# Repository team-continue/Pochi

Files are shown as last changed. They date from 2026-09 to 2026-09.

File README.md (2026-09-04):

# Pochi
CoREストライダー部門用のロボット「Pochi」のメインレポジトリです。

詳細はドキュメントサイトを参照してください。

## 開発ルール
開発はブランチを切って Pull Request で main にマージしてください。main への直接コミットは禁止です。
ブランチ名: 機能追加は feature/hogehoge、バグ修正は fix/hogehoge
パッケージ名: pochi_hoge（タブ補完で一覧表示できるように）
Formatting (CI)
Push 時に CI が ament_clang_format を実行し、必要ならブランチへ自動コミットします。 main ブランチには自動 push しません。

## ビルド
``` shell
cd ~/ros2_ws
source /opt/ros/humble/setup.bash
rosdep install --from-paths src -i -y
colcon build --symlink-install
source install/setup.bash
```

## 起動方法
```
# シミュレータモード（デフォルト: /sim_odom使用）
ros2 launch core_launch navigation.launch.py

# シミュレータ + FAST-LIOオドメトリ
ros2 launch core_launch navigation.launch.py odom_source:=fastlio

# 実機モード（FAST-LIO + body_controller、TCP endpoint無し）
ros2 launch core_launch navigation.launch.py environment:=real

# 実機モード（GUI・ショートカットから）
# .bashrc が非対話シェルで早期 return するため、このラッパーを使用
ros2 run core_launch navigation.sh

# ボディコントローラ単体
ros2 launch core_launch navigation.launch.py environment:=real map_name:=curious_house.png

```
Launch 引数の詳細はドキュメントサイトの「クイックスタート」を参照してください。

実機ハードウェア、Teensy通信、Web joint viewerのセットアップは
[`pochi_hardware/README.md`](pochi_hardware/README.md)を参照してください。

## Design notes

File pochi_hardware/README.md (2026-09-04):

# Pochi Hardware

Pochiの回路、STM32/Teensyファームウェア、ホスト側通信ツール、Python API、
Web joint viewerをまとめています。

## Python APIとWeb joint viewer

`pochi_client`はTeensy USB/UDP bridgeと通信するPython APIです。12台分のMIT指令を
1 packetで送信し、12台の状態とIMUを1 packetで受信します。Web viewerは左側の
3Dモデルへ現在姿勢を反映し、右側から関節の選択・目標角度・全体Torque ON/OFFを
操作できます。

### セットアップ

```bash
cd ~/Documents/GitHub/Pochi
uv sync

cd pochi_hardware/web
npm install
```

### Web joint viewer

3つのターミナルを使います。

#### 1. USB/UDP bridge

macOSではTeensyのdevice名を確認して起動します。

```bash
cd ~/Documents/GitHub/Pochi
uv run python pochi_hardware/src/teensy_udp_bridge.py \
  --serial /dev/cu.usbmodem176277501 \
  --command-bind 127.0.0.1:15000 \
  --state-dest 127.0.0.1:15001
```

#### 2. UDP/WebSocket server

```bash
cd ~/Documents/GitHub/Pochi
uv run python -m pochi_hardware.web.server
```

状態確認用URLは`http://127.0.0.1:8765/health`、WebSocketは
`ws://127.0.0.1:8765/ws`です。

#### 3. Web UI

```bash
cd ~/Documents/GitHub/Pochi/pochi_hardware/web
npm run dev
```

ブラウザで`http://127.0.0.1:3000`を開きます。

### Viewer controls and safety

- 左の3Dモデルは12軸の実角度を常時反映します。ドラッグで視点回転、スクロールでズーム、関節をクリックすると選択できます。
- 右の関節一覧または3Dモデルから1軸を選び、スライダーでMIT controlの目標角を更新します。
- `TORQUE ON`は全12台の現在角を初期目標に設定してから全軸をEnableします。
- 全12台から有効なCAN feedbackが返り、Faultがないときだけ`TORQUE ON`できます。
- 最後のWeb画面を閉じた場合、WebSocket serverは全軸を自動Disableします。
- WebSocket server終了時は全軸Disableとemergency-stop packetを送ります。
- Hip/Thigh/Calfの暫定UI制限はそれぞれ±55°、±150°、-165〜25°です。機構限界確定後にWeb UIとserverの両方を更新してください。

### Client API

```python
from pochi_client import PochiClient

with PochiClient() as robot:
    state = robot.wait_for_state(timeout=1.0)
    robot.set_mit(
        "front_left_hip",
        position_rad=0.2,
        velocity_rad_s=0.0,
        kp=20.0,
        kd=0.5,
        torque_nm=0.0,
        enable=True,
    )
    robot.disable_all()
```

### Joint layout

脚とCAN IDの対応です。各脚では足先側からIDが増えます。

| Leg | Hip | Thigh | Calf |
| --- | ---: | ---: | ---: |
| Front left | 2 | 1 | 0 |
| Rear left | 5 | 4 | 3 |
| Rear right | 8 | 7 | 6 |
| Front right | 11 | 10 | 9 |

Web画面には誤認防止のためCAN IDを常時表示します。

### テストとWebビルド

```bash
cd ~/Documents/GitHub/Pochi
uv run pytest -q

cd pochi_hardware/web
npm run build
```

## Jetson Orin NanoのSPI0ピン設定

`systemd/pochi-spi0-pinmux.service`は、Jetson Orin Nanoの40ピンヘッダーにある
SPI0をPochi用に設定します。

使用する物理ピンは次の4本です。

| 物理ピン | 信号 |
| --- | --- |
| 19 | SPI0 MOSI |
| 21 | SPI0 MISO |
| 23 | SPI0 SCK |
| 24 | SPI0 CS0 |

### インストールと有効化

以下は、この`pochi_hardware`ディレクトリで実行します。

```bash
sudo install -o root -g root -m 0644 \
  systemd/pochi-spi0-pinmux.service \
  /etc/systemd/system/pochi-spi0-pinmux.service

sudo systemctl daemon-reload
sudo systemctl enable --now pochi-spi0-pinmux.service
sudo systemctl restart pochi-spi0-pinmux.service
```

状態を確認します。

```bash
systemctl is-enabled pochi-spi0-pinmux.service
systemctl is-active pochi-spi0-pinmux.service
```

それぞれ`enabled`と`active`になれば設定完了です。

### STM32との通信確認

STM32へSPIエコーファームウェアを書き込んだ状態で、Orinから20 MHzのテストを
実行します。

```bash
cd ~/pochi
./orin_spi_test /dev/spidev0.0 20000000
```

成功時は次のように表示されます。

```text
TX=DE AD BE E1  ECHO=DE AD BE E1
PASS: STM32 echoed the Orin request
```

### 停止とGPIO設定の復元

サービスを停止すると`ExecStop`が実行され、SPIパッドを開発用Orinで取得した
元のGPIO設定へ戻します。

```bash
sudo systemctl disable --now pochi-spi0-pinmux.service
```

サービス自体も削除する場合は、停止後に次を実行します。

```bash
sudo rm -f /etc/systemd/system/pochi-spi0-pinmux.service
sudo systemctl daemon-reload
```

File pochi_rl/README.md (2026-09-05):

# Pochi RL

Standalone uv-managed reinforcement-learning project for the Pochi quadruped.
Phase 1 targets mjlab with a starter 4-leg x 3-DoF MJCF and a flat-ground
velocity-tracking PPO task. Phase 2 can add Isaac Lab configs while reusing the
same `task_spec.py` and robot constants.

## Setup

```bash
cd /home/k_suzuki/fun_ws/Pochi/pochi_rl
uv sync
uv pip install -e .
```

## Inspect the Robot

```bash
uv run python scripts/view_mjcf.py
```

## Train

Single GPU:

```bash
MUJOCO_GL=egl uv run train Pochi-Velocity-Flat-v0 \
  --env.scene.num-envs 4096 \
  --agent.max-iterations 1500 \
  --agent.experiment-name pochi_velocity_flat
```

Multi GPU:

```bash
MUJOCO_GL=egl uv run train Pochi-Velocity-Flat-v0 \
  --env.scene.num-envs 4096 \
  --gpu-ids "[0,1]"
```

Playback:

```bash
uv run play Pochi-Velocity-Flat-v0 \
  --checkpoint-file logs/rsl_rl/pochi_velocity_flat/<ts>/model_1500.pt \
  --num-envs 1
```

Export:

```bash
uv run python scripts/export_policy.py \
  --checkpoint logs/rsl_rl/pochi_velocity_flat/<ts>/model_1500.pt \
  --output exports/
```

## Notes

- The MJCF uses primitive collision/visual geometry only. Keep collision
  primitives when CAD meshes arrive unless a task needs detailed contacts.
- Joint names and action order are defined in
  `src/pochi_rl/robot/pochi_constants.py`.
- The default control path is MuJoCo position actuators with `kp=40`,
  `forcerange="-30 30"`, and policy deltas scaled by `action_scale=0.25`.
- Masses, inertias, dimensions, joint limits, and the default crouch are starter
  values and should be replaced with CAD/hardware values before sim-to-real.

## MPC Walking (No Training)

```bash
uv run --extra mpc python scripts/play_mpc_walk.py --port 8092
```

Open `http://localhost:8092` for live MuJoCo walking with MPC trajectory and
contact-force overlays. See [MPC_WALK.md](MPC_WALK.md) for evaluation, controls,
and the controller's scope.

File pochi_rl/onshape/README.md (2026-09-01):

# Onshape CAD Import

Exports the Pochi CAD assembly from Onshape to MJCF using
[onshape-to-robot](https://onshape-to-robot.readthedocs.io/).

## Setup (once)

1. Create API keys at <https://cad.onshape.com/user/developer/apiKeys>.
2. `cp .env.example .env` and fill in the keys (`.env` is gitignored).
3. Paste the Onshape **assembly** URL into `config.json` (`url`).

## Export

```bash
cd pochi_rl
uv run onshape-to-robot onshape/
```

Outputs `onshape/pochi_cad.xml` plus meshes in `onshape/assets/`. Preview with:

```bash
uv run onshape-to-robot-mujoco onshape/
```

## Required conventions in the Onshape assembly

onshape-to-robot derives the robot structure from mate-connector names
(see the [design page](https://onshape-to-robot.readthedocs.io/en/latest/design.html)).
Names must match `src/pochi_rl/robot/pochi_constants.py` so the exported model
is a drop-in for the training pipeline:

- The **first instance** in the top-level assembly is the base link. Attach a
  mate connector named `link_base_link` to name it `base_link`.
- **Joints** (12): revolute mates named `dof_<LEG>_<KIND>` for each leg
  `FL, FR, RL, RR` and kind `hip_roll, hip_pitch, knee`
  (e.g. `dof_FL_hip_roll`). Joints rotate around the mate's z-axis; append
  `_inv` (e.g. `dof_FL_knee_inv`) where needed to match the sign conventions
  in `assets/pochi/README.md`: hip pitch positive swings the leg backward,
  knee positive swings the shank backward, hip roll positive swings
  both legs to the robot's left.
- **Sites**: mate connectors `frame_FL_foot_site`, `frame_FR_foot_site`,
  `frame_RL_foot_site`, `frame_RR_foot_site` at the foot centers, and
  `frame_imu` on the torso. These become MuJoCo sites.
- Frames: torso x-forward, y-left, z-up.

## Integration into training assets

Per project policy (`assets/pochi/README.md`), CAD meshes replace **visual**
geoms only; the primitive **collision** geoms in `assets/pochi/pochi.xml`
(`<LEG>_foot_collision`, `<LEG>_thigh_collision`, `<LEG>_shank_collision`,
`base_collision`) stay, because the contact sensors and rewards in
`velocity_flat_env_cfg.py` reference them by name. After a satisfactory
export:

1. Compare masses/inertias/joint placements against `pochi.xml` and update the
   hand-written model with the CAD values.
2. Copy meshes into `assets/pochi/meshes/` and reference them as visual geoms.
3. `uv run pytest` — `test_mjcf_loads.py` pins joint/actuator/body counts.

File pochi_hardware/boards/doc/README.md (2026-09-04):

# Hardware reference documents

2026-08-23 に `main_1` 回路図を照合するため収集した資料です。
可能なものはメーカー公式PDFを保存し、メーカーサイトが直接取得を拒否する場合のみ、同一メーカー文書の配布ミラーを利用しています。

| 対象 | ローカル資料 | 公式の最新版・製品ページ | 備考 |
|---|---|---|---|
| STM32G474CB | `ST_STM32G474_datasheet.pdf` | https://www.st.com/resource/en/datasheet/stm32g474cb.pdf | DS12288 Rev.6 |
| STM32G4 hardware guide | 未保存 | https://www.st.com/resource/en/application_note/an5093-getting-started-with-stm32g4-series--hardware-development-boards-stmicroelectronics.pdf | AN5093 Rev.2。STサーバーがCLI取得を拒否するためリンクのみ |
| ICM-45686 | `TDK_ICM-45686_datasheet.pdf` | https://invensense.tdk.com/wp-content/uploads/documentation/DS-000577_ICM-45686.pdf | DS-000577 Rev.1.0。配布ミラーから保存 |
| S9012 / C8543 | `JSCJ_S9012_C8543_datasheet.pdf` | https://www.jscj-elec.com/gallery/file/AD-S9012%20series.pdf | メーカー公式PDF。C8543はSOT-23、hFE 200–350品 |
| SMCJ43A | `Bourns_SMCJ_datasheet.pdf` | https://www.bourns.com/docs/Product-Datasheets/SMCJ.pdf | 同一電気仕様のBourns公式シリーズ資料。採用時はメーカーとMPNを固定する |
| DDZ9699 12 V Zener | `Diodes_DDZ9699_datasheet.pdf` | https://www.diodes.com/part/view/DDZ9699 | LTC4359のGATE–SOURCE保護候補、SOD-123 |
| RobStride discharge module | `RobStride_discharge_module_manual_V1.1.pdf` | https://github.com/RobStride/Product_Information/tree/main/%E4%BA%A7%E5%93%81%E8%B5%84%E6%96%99/dischargeModule | 15–60 V、48 Vモードは53.5 Vで泄放開始。3 Ω/500 W～10 Ω/200 Wを推奨 |
| RobStride power board | `RobStride_power_board_manual_V1.5.pdf` | https://github.com/RobStride/Product_Information/tree/main/%E4%BA%A7%E5%93%81%E8%B5%84%E6%96%99/powerBoard | 20–65 V、4支路、プリチャージ・泄放・過流保護の構成参考 |
| TPS5430 | `TI_TPS5430_datasheet.pdf` | https://www.ti.com/lit/ds/symlink/tps5430.pdf | 公式PDF |
| ISO1044 | `TI_ISO1044_datasheet.pdf` | https://www.ti.com/lit/ds/symlink/iso1044.pdf | 公式PDF |
| ADuM120N/ADuM121N | `ADI_ADuM120N_ADuM121N_datasheet_RevE.pdf` | https://www.analog.com/media/en/technical-documentation/data-sheets/ADuM120N_121N.pdf | ローカルはRev.E。設計判断は公式Rev.Fを参照 |
| LTC4359 | `ADI_LTC4359_datasheet_RevE.pdf` | https://www.analog.com/media/en/technical-documentation/data-sheets/ltc4359.pdf | ローカルはRev.E。設計判断は公式Rev.Fを参照 |
| HT75xx-1 | `Holtek_HT75xx-1_datasheet.pdf` | https://www.holtek.com/webapi/116711/HT75xx-1v130.pdf | 公式PDF |
| MAU100 series | `MINMAX_MAU100_datasheet.pdf` | https://www.minmaxpower.com/storage/media/Product-MINMAX/MAU100/Document/MAU100_Datasheet.pdf | 公式PDF |
| SP3485 | `MaxLinear_SP3485_datasheet.pdf` | https://www.maxlinear.com/ds/sp3485.pdf | 公式PDF |
| SP481E/SP485E | `MaxLinear_SP481E_SP485E_datasheet.pdf` | https://www.maxlinear.com/ds/sp481e_sp485e.pdf | 公式PDF |
| IPT015N10NF2S | `Infineon_IPT015N10NF2S_datasheet.pdf` | https://www.infineon.com/part/IPT015N10NF2S | 公式PDF |
| 2N7002 | `onsemi_2N7002_datasheet.pdf` | https://www.onsemi.com/pdf/datasheet/2n7002-d.pdf | 公式PDF |
| Epson水晶型番体系 | `Epson_crystal_product_configuration.pdf` | https://www.epsondevice.com/crystal/en/support/product-no/pdf/pcs_xtal.pdf | Y1の正確な型番決定用 |
| Littelfuse SMDJ | 未保存 | https://www.littelfuse.com/assetdocs/littelfuse-tvs-diode-smdj-datasheet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 | 公式サーバーがCLI取得を403拒否するためリンクのみ |
| Jetson Orin Nano carrier | `NVIDIA_Jetson_Orin_Nano_carrier_spec.pdf` | https://developer.nvidia.com/embedded/downloads | 40-pin header照合用 |
| JST VH | `JST_VH_connector_datasheet.pdf` | https://www.jst-mfg.com/product/pdf/eng/eVH.pdf | 公式PDF |

## 注意

- `ADuM121N`、`SP485E`、`S9012`、水晶Y1は、回路図上の型番だけでは注文型番を一意に決められません。温度範囲、フェイルセーフ状態、パッケージ、負荷容量を含む完全なMPNが必要です。
- 抵抗、コンデンサ、インダクタにも定格電圧・許容損失・温度特性を含むMPNを割り当てないと、48V系と電源回路の最終判定はできません。

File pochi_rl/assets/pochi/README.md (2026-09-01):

# Pochi MJCF Conventions

`pochi.xml` and everything in `meshes/` are **generated** from the Onshape CAD
export by `scripts/glb_to_mjcf.py`. Edit the converter, not the XML:

```bash
uv sync --group cad
uv run python scripts/glb_to_mjcf.py --report
```

The primary input is **`pkg_4leg_assem2/`**, the onshape-to-robot URDF export.
It carries both halves of what the model needs:

- **Kinematics**, from the twelve `dof_<LEG>_<KIND>` mates. Their axes are
  explicit, so nothing is inferred.
- **Part masses**, as Onshape computed them from the materials assigned in CAD.

The export is *flat*: onshape-to-robot turns every untagged Onshape mate into a
joint, so the file holds ~1600 spurious prismatic/cylindrical joints for bolts
sitting in holes (1629 links, 1628 joints, 516 loop closures). Those are rigid
in reality, so `pochi_rl.cad.urdf` cuts the tree only at the twelve `dof_` mates
and welds the rest into the thirteen links. Their zero *is* the assembled pose,
so forward kinematics reproduces the CAD: all four legs come out identical to
within 0.1 mm.

`4leg_assem2.glb` remains as a fallback (`--source glb`), which recovers the
joint axes from the twelve RS02 placements instead. It agrees with the URDF's
explicit mates to 0.0002° in axis direction, which is what validated the
inference in the first place.

The RS02 is the one part with no material assigned in CAD (the URDF reports
0.18 g), so it keeps the datasheet mass. `--no-urdf-masses` falls back to
guessing a density per part name; that agrees within 2 % everywhere except
`Part 1`, which is printed plastic at ~1050 kg/m³ rather than the guessed
aluminium -- 0.8 kg of the robot. The GLB carries no kinematics, so joint axes and origins are recovered
from the twelve RobStride RS02 actuators: each motor's local `+z` is its output
axis. `Body_2` carries the four hip roll motors, each `Hiproll_1` carries a hip
pitch motor, and each `Hippitch_1` carries a knee motor.

## Frames and conventions

- Torso: x forward, y left, z up. The base origin sits at the centre of the four
  hip joints, at hip height.
- Leg labels `FL, FR, RL, RR`; joint names `<LEG>_<KIND>` with kind
  `hip_roll`, `hip_pitch`, `knee`. Action order is `JOINT_NAMES` from
  `pochi_rl.robot.pochi_constants`.
- Sign convention: hip roll positive swings both legs to the robot's left, hip
  pitch positive swings the thigh backward, knee positive swings the shank
  backward relative to the thigh.
- Zero pose: every leg straight down. The CAD ships with the legs folded flat;
  each link is rotated back about its own joint axis during conversion.
- Default stance (`DEFAULT_JOINT_POS`) mirrors front and rear, matching how the
  CAD is assembled: front hip pitch `+0.8` / knee `-1.5`, rear `-0.8` / `+1.5`.
  That balances the load across the four feet (26.8 N each) and puts the COM
  over the base centre; a uniform stance shifts it 41 mm rearward.

## Geometry (from CAD)

| quantity | value |
| --- | --- |
| hip joint offset from base centre | ±0.2545 m fore/aft, ±0.070 m lateral |
| thigh (hip pitch axis → knee axis) | 0.200 m |
| shank (knee axis → foot tip) | 0.225 m |
| foot lateral offset from leg plane | 0.098 m outboard |
| foot pad | 16 mm wide, ~19 mm radius fore/aft |
| total mass | 10.92 kg (7.92 CAD + 3.0 ballast) |

The hip roll and hip pitch axes intersect, so both hip joints share an origin
and the thigh body sits at the hip body origin. All four legs are kinematically
identical — the fore/aft difference in the CAD is only how the assembly was
posed, plus the hip housings facing inboard.

## Actuators

Every joint is a RobStride RS02. The datasheet numbers live in
`src/pochi_rl/robot/pochi_constants.py` and are shared by every backend:

| quantity | value |
| --- | --- |
| peak (stall) torque | 17 N·m |
| rated (continuous) torque | 7 N·m @ 100 rpm |
| no-load speed | 410 rpm = 42.9 rad/s at the output shaft |
| gear ratio | 7.75:1 |
| mass | 0.405 kg |

`pochi.xml` gives its `<position>` actuators a flat ±17 N·m `forcerange`, which
is all a standalone MJCF can express. Under mjlab those actuators are deleted
(`pochi_rl.mjlab.entity_cfg.pochi_spec`) and replaced by `DcMotorActuatorCfg`
`<motor>` actuators, so the torque is clamped to the real torque-speed curve —
peak torque only near zero speed, falling to zero at the no-load speed — instead
of being available at any joint velocity. This is a constraint in the actuator
path, not a reward penalty. `effort_limit` is set to the peak torque, so only
the curve binds; setting it to `RS02_RATED_TORQUE_NM` would additionally enforce
the continuous rating.

## Torso ballast

The bare CAD torso is light for the machine, so `PAYLOAD_MASS_KG = 3.0` adds a
ballast block to the base link, standing in for the battery, electronics and any
trim weight the real robot carries. It sits at the base origin (the hip centre),
so the COM stays over the support polygon. It is modelled as a steel cube -- the
density sets its size and hence its rotational inertia, which a bare point mass
would leave at zero and make the torso far too easy to spin. Set the constant to
0 to get the bare CAD robot back, or move it with `PAYLOAD_POS` once the real
payload's location is known.

## Assumptions to revisit

- **RS02 mass** is the datasheet 0.405 kg (`RS02_MASS_KG`). The OpenELAB guide
  quotes 405 g ±5 g and the RobStride repo 380 g ±3 g; twelve of them are 56 % of
  the robot mass, so replace it with a weighed value.
- Other masses come from Onshape via the URDF export. `DENSITIES` in
  `src/pochi_rl/cad/convert.py` is only the fallback for when that export is
  absent; it reads 0.8 kg heavy because it assumes `Part 1` is aluminium.
- **Joint ranges are placeholders** (`JOINT_RANGES` in
  `src/pochi_rl/cad/convert.py`): the CAD encodes no end stops. They are wide
  enough to reproduce the folded CAD pose; tighten them once the hardware
  limits are known.
- **Ballast position and extent** are a placeholder: 3 kg of steel at the hip
  centre. Replace with the real battery/electronics mass and location.
- Actuator gains (`kp = 60`, `kv = 1.5`) are hand-picked, not derived. The
  mjlab reference robots instead derive them from the reflected rotor inertia
  and a target closed-loop bandwidth, which for Pochi would give roughly
  `kp = 39.5`, `kv = 2.5`.
- **Rotor inertia** (`RS02_REFLECTED_INERTIA`, the joint `armature`) is an
  estimate; the datasheet does not publish it.
- Collision geometry is primitives (box torso and hips, capsule limbs) except
  the **foot pads**, which collide as the convex hull of the CAD part itself
  (`<LEG>_foot_pad.obj`). The pad is a printed part 16 mm wide with a ~19 mm
  radius profile fore/aft, so a sphere got the lateral contact wrong; the hull
  keeps the real footprint. `convert.foot_pad_part` finds it by geometry -- the
  shank part owning the vertex farthest from the knee axis -- not by name.
  Everything else's mesh is visual-only.

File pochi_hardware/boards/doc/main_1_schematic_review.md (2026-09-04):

# main_1 schematic review

Review date: 2026-08-23  
Scope: `main_1.kicad_sch`, `MCU.kicad_sch`, `Power.kicad_sch`  
Excluded: PCB layout/routing (requested separately)

## 結論

現状は **製造・発注前OKではありません**。KiCadネットリスト、ERC、主要部品のデータシートを照合した結果、電源経路と信号経路に複数の必須修正があります。

## P0: 製造前の必須修正

1. **U2 ICM-45686のシンボルとピン番号を作り直す**
   - 実部品は14-pin LGAです。現シンボルは12ピンしかなく、例として現回路のpin 2=3V3、pin 3=GND、pin 4=SCKですが、実部品はpin 5=VDDIO、pin 6=GND、pin 8=VDD、pin 13=AP_SCLK、pin 14=AP_SDI、pin 1=AP_SDOです。
   - VDDとVDDIOそれぞれに0.1uFを直近配置します。
   - SPI配線は PA4=NSS、PA5=SCK、PA6=MISO、PA7=MOSI の方針自体は妥当です。

2. **J11/J12の48V入力マイナスをGNDPWRへ接続する**
   - J11 pin 1はD4片端との2端子ネット、J12 pin 1はD5片端との2端子ネットで止まり、GNDPWRへ接続されていません。
   - D4/D5を入力+48VとGNDPWR間のTVSにし、XT60のマイナスをGNDPWRへ直結します。

3. **Q3 drainを+48V/U13 OUTへ接続する**
   - 現在Q3 drainは `Net-(Q3-D)` に孤立し、+48Vへ到達しません。48V1側の理想ダイオード経路が切れています。

4. **STM32と絶縁UARTのネット名を統一して接続する**
   - U5 PB10=`/MCU/TTL_TX` と U10 VIB=`/MCU/UART_TX_IN` は別ネットです。
   - U5 PB11=`/MCU/TTL_RX` と U10 VOA=`/MCU/UART_RX_IN` も別ネットです。
   - 各ネットは現在それぞれ1ピンだけで、UART回路はSTM32へ接続されていません。

5. **MCUシートとPowerシートのCANネットを意図どおり接続する**
   - `/MCU/CAN1_H` と `/Power/CAN1_H`（CAN2/CAN3も同様）は階層ローカルラベルなので別ネットです。
   - 同じCANバスにするなら、階層シートピンまたはグローバルラベルで接続します。外部RJ45ケーブルでJ10とJ19を接続する設計なら、その前提を明記します。
   - Power側CANコネクタの基準GNDはGNDPWR、ISO1044のバス側はGNDDです。同じバスならコネクタのGNDもGNDDに揃える必要があります。

6. **D7/D8/D10を正しいゲート保護部品に置換する**
   - 現状はShockley diodeシンボル、値はMOSFETの `IPT015N10NF2SATMA1`、footprintはSOD-323で、BOMとして成立しません。
   - ゲート・ソース間クランプを意図するなら、電圧を決めた実在Zener/TVSのMPN、Zenerシンボル、対応footprintへ置換します。LTC4359には内部ゲートクランプもあるため、外付け要否も再判断します。

7. **C35 10000uF/50Vを再選定する**
   - 48Vレールに50V品は定常電圧の余裕がほぼありません。SMDJ48Aの最大クランプは77.4Vなので、C35はサージ時に定格超過します。
   - 最大入力電圧、TVSクランプ、温度・寿命ディレーティングから、少なくとも63V以上、条件次第で80V級を検討します。10000uFの突入電流対策も必要です。

8. **Q1のC/E接続を修正・確認する**
   - 現ネットリストではQ1 collectorが+5VP、emitterがU11 DE/REです。PNP高側駆動を意図するなら通常はemitter=+5VP、collector=DE/RE側です。
   - S9012はメーカーでピン配列が異なるため、完全なMPNを指定してシンボルとfootprintを照合します。

9. **MotorPWRのSHDN既定状態を仕様と照合する**
   - 48V時、R21+R22=30k/R23=4.7kでQ5 gateは約6.5Vとなり、Q5がU14 SHDNをLowへ引いてMotorPWRをOFFにします。
   - 「外部入力をLowにした時だけON」が仕様なら説明を追加します。電圧監視が目的なら2N7002のVGS(th)依存では精度が出ないため、コンパレータ/スーパーバイザへ変更します。

## P1: 重要な再設計・定格確認

- **U3 HT7533-1**: シンボルとデータシート欄がMCP1703のままです。HT7533-1の保証電流に対し、170MHz STM32、ICM、3個のISO1044一次側、ADuM、SP3485を含む3.3V負荷のワーストケース電流表を作成してください。余裕がなければ高電流LDOへ変更します。
- **VREF+/VDDA**: VDDAの10nF+1uFとフェライト経路は概ね妥当ですが、VREF+は+3V3へ直結され、データシート推奨の専用100nF+1uFがありません。ADC精度を使うなら追加します。L2は「600Ω」だけでなく、フェライトビーズの周波数条件・電流定格・MPNを指定します。
- **Y1**: 値は16MHz/9pFですが、登録URLの秋月 `P-02458` は20MHz品です。16MHz品またはEpsonの完全なMPNへ修正し、実際のCLと基板寄生容量からC8/C11を再計算します。
- **C4/C12**: C4は値欄が10u/0603/25Vなのにfootprintは0402です。C12の10uF/0402もDCバイアス低下が大きいため、実MPNの容量曲線で確認し、0603/0805を検討します。
- **SMDJ48A**: VRWM=48V、VBR=53.3～58.9V、VC=77.4Vです。「48V」がバッテリ公称値なら満充電電圧が48Vを超える可能性があるため、最大連続電圧基準でTVSを再選定します。
- **CAN/RS-485終端**: R7/R8/R9とR1の120Ωは常時実装です。この基板が必ずバス終端でない限り、jumper/DNPで選択式にします。外部配線にはCAN/RS-485用TVS/ESD保護も検討します。
- **MAU102**: 5V→5V/1W/200mA、出力容量上限10uFに対しC24=1uFは範囲内です。ただし非安定化出力なので、ISO1044×3、ADuM、SP485Eの最小/最大負荷で+5VP電圧を確認します。
- **ADuM121N/SP485E**: フェイルセーフ状態、温度範囲、パッケージを含む完全な注文型番を指定します。
- **LED抵抗**: 3.3V駆動のR6=47kはLED電流が極小で、視認性が不足する可能性が高いです。48V側R14/R15=47k・0402は約1mA/約49mWなので、抵抗の定格電圧と温度ディレーティングを確認し、直列分割または大きいpackageを検討します。
- **部品参照**: `QIPT015N10NF2SATMA1` は参照番号として不正です。通常のQ番号へ直し、値を実MPNにします。

## 確認できた妥当な部分

- TPS5430のR3=10k/R4=3.24kは約4.99V設定で、D1、L1、bootstrap capacitorの接続方向は妥当です。入力・出力コンデンサの電圧定格と実MPNは別途必要です。
- ISO1044×3は一次3.3V、二次+5VP、両側100nFの構成が取れています。
- MAU102のpin 1=+5V、pin 2=GND、pin 4=GNDD、pin 6=+5VPはデータシートと一致します。
- Orin J3 pin 12からR24を介してQ6 gateを駆動し、Q6 drainでNRSTをLowへ引くオープンドレイン構成、R25=100k gate pulldown、C7=100nF reset filterは妥当です。
- BOOT0はJ3 pin 29からR26=1kを介し、R2=10k pulldown付きです。J3 pin 27ではなくpin 29を使う現在の回路で妥当です。

## ERC

KiCad 10.0.3で27件（error 9、warning 18）を検出しました。ライブラリコピー不一致の警告も含みますが、1ピンだけのUARTラベルは実際の未接続を示しています。修正後はERC error=0を目標に再実行してください。

## 推奨修正順

1. ICM-45686シンボル、48V入力GND、Q3 drain、UART/CANネットを修正
2. D7/D8/D10、Q1、MotorPWR SHDN、C35/TVSを確定
3. U3電流予算、VREF、Y1、受動部品定格とMPNを確定
4. ERCを0 errorまで再確認
5. その後にPCBレビュー（クリアランス、電流容量、熱、絶縁、リターン経路）へ進む

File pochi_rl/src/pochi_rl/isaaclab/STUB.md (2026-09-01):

# Isaac Lab Phase 2 Stub

Add the Isaac Lab backend here without moving Phase 1 files:

1. Add `assets/pochi/pochi.urdf` with joint names matching `JOINT_NAMES`.
2. Convert the URDF to `assets/pochi/pochi.usd` through Isaac Sim.
3. Add `pochi_articulation_cfg.py`, `velocity_flat_env_cfg.py`, and matching
   RSL-RL PPO config under this package.
4. Register `Pochi-Velocity-Flat-IsaacLab-v0`.

The shared source of truth remains `pochi_rl.task_spec` and
`pochi_rl.robot.pochi_constants`.

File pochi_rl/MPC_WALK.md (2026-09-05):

# MPC walking

RLと独立した、平地用の低速クロール歩行です。学習済み重みは不要です。
生成済みCADモデルをそのまま使い、自由浮遊する胴体を関節トルクだけで
支えます。接触・重力・摩擦はMuJoCoが計算します。

## 表示

```bash
cd /home/k_suzuki/fun_ws/Pochi/pochi_rl
uv run --extra mpc python scripts/play_mpc_walk.py --port 8092
```

ブラウザで `http://localhost:8092` を開いてください。他のPCからは
ホストのLANアドレスを使えます。既にポートが使用中ならviserが空きポートを
選ぶので、起動ログに出るURLを確認してください。

- 水色: MPCの予測重心軌道（16ステップ、0.8秒先まで）
- 黄色: 目標重心軌道、紫色: 実際の重心の軌跡
- オレンジ: 足先目標、緑色: 最適化した接地力
- Controlsタブ: 一時停止、リセット、再生速度
- Walking speed: 変更後にResetすると新しい速度で開始

既定は0.06 m/sで前進し、30秒ごとに初期位置に戻って繰り返します。
`--loop-duration 0` で連続歩行、`--speed -0.06` で後退できます。

## 数値評価

```bash
uv run --extra mpc python scripts/eval_mpc_walk.py \
  --duration 30 --output logs/mpc_walk/evaluation.json
uv run --extra mpc pytest tests/test_mpc_walk.py
```

評価は距離、姿勢、トルク、足先クリアランス、足以外の床接触、QPの成否を
JSONで出力します。転倒や追従誤差などの基準を満たさない場合は終了コード1です。

## 構成と適用範囲

`control/centroidal_mpc.py` は位置・姿勢・速度の12次元状態を用い、20 Hzで
有限時間の凸二次計画を解きます。接地スケジュール、片側接触、摩擦錐に内接する
摩擦ピラミッド、垂直接地力の上限を制約にします。毎回、実測状態から計画し直し、
最初の接地力だけを適用します。未来の遊脚予定も現在の力配分に影響します。
ソルバーは[OSQP](https://osqp.org/docs/interfaces/python.html)です。

`control/mpc_walk.py` はFR→RL→FL→RRの固定接地順序、速度に応じた着地点、
端点速度ゼロの遊脚軌道を生成します。支持脚にはヤコビアン転置で接地力を
関節トルクへ変換し、遊脚には足先インピーダンス制御を適用します。
MuJoCo物理と関節制御は200 Hzです。関節トルクは既存RS02のピーク17 Nmと
回転速度の包絡線に制限します。モデルXMLやRLの環境・報酬は変更しません。

このMPCが最適化するのは重心軌道と接地力です。接地順序・着地点そのものの
最適化や、段差・旋回・実機の状態推定は含みません。単一剛体と小角度近似を
使うため、まずは付属の平地と低速設定で利用してください。関節限界は物理モデル、
モータ制限はトルク適用時に扱い、QPの実行可能性は全身の実行可能性を保証しません。
実機投入前には連続定格、状態推定、接触検出など別途対応が必要です。

## 確認結果

既定設定の60秒評価では、目標3.48 mに対して3.4786 m前進、最大傾き
0.90°未満、最大関節トルク6.91 Nm未満、足以外の床接触0 N、QP失敗0回でした。
MPCと共有モデルの関連テストは19件成功（CADデータ依存の4件はスキップ）。
これは付属の平地モデルでのシミュレーション結果です。

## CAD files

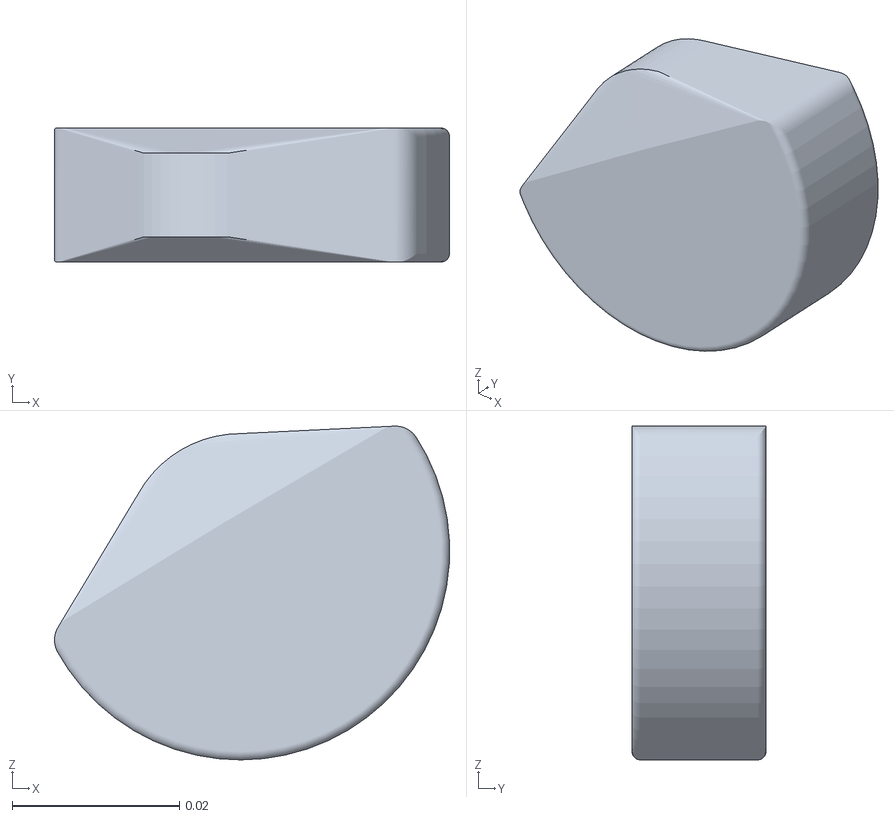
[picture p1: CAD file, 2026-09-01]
pochi_rl/assets/pochi/meshes/RL_foot_pad.obj
0.0472 x 0.016 x 0.0399

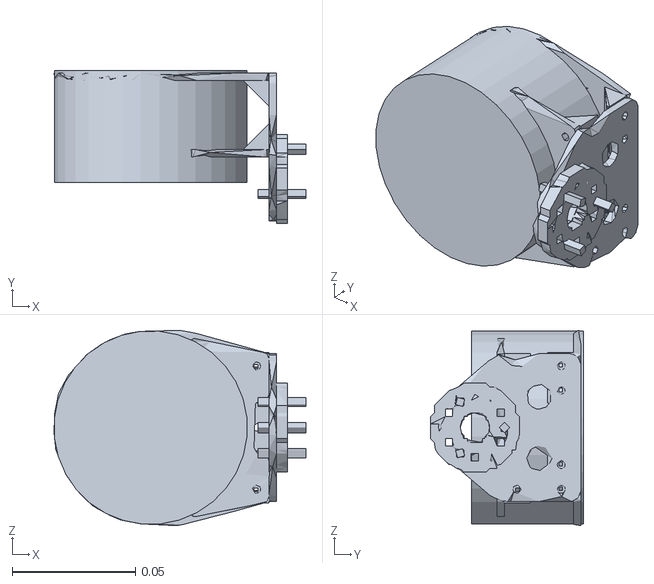
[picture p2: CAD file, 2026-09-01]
pochi_rl/assets/pochi/meshes/RL_hip.obj
0.102 x 0.062 x 0.0792

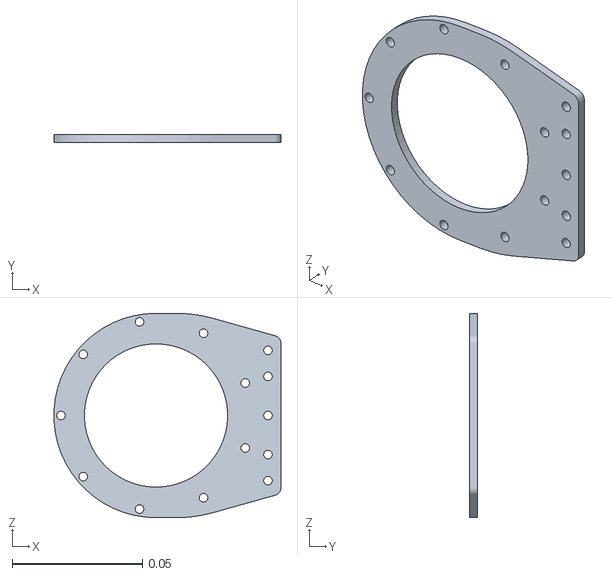
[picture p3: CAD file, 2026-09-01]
pochi_rl/pkg_4leg_assem2/meshes/carbon_plate_hip_2__3mm_x4_.stl
0.0872 x 0.003 x 0.0785

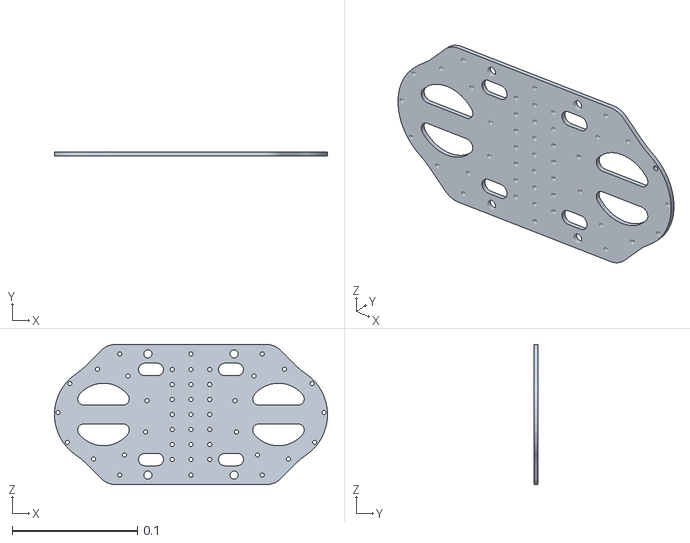
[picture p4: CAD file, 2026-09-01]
pochi_rl/pkg_4leg_assem2/meshes/carbon_Body_plate3_x__3mm_x2_.stl
0.218 x 0.003 x 0.112

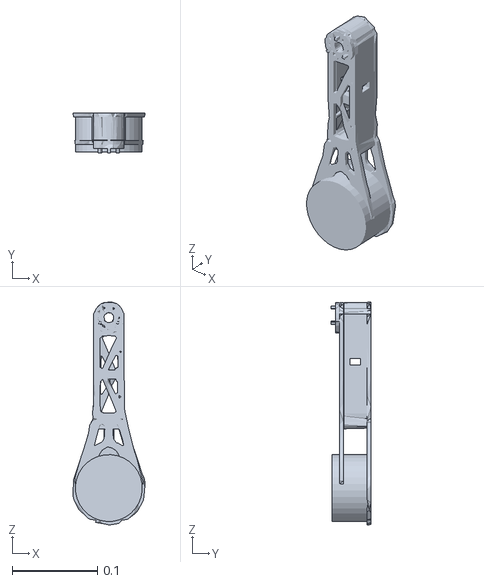
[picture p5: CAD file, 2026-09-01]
pochi_rl/assets/pochi/meshes/RL_thigh.obj
0.0843 x 0.047 x 0.262

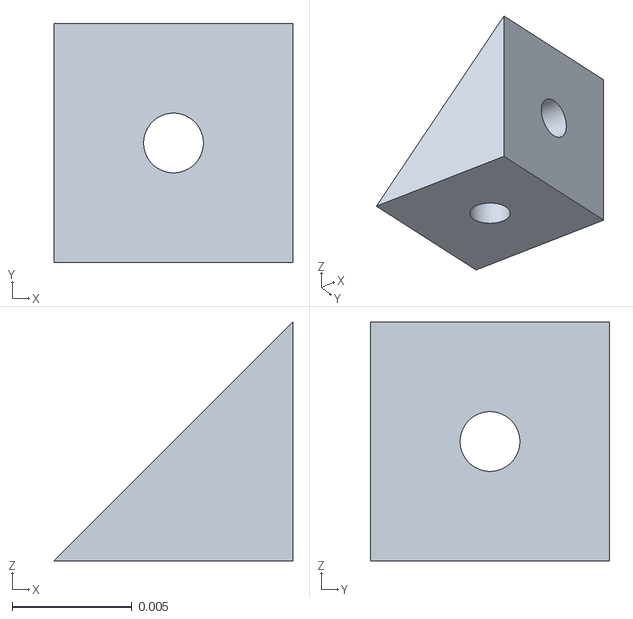
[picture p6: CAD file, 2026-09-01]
pochi_rl/pkg_4leg_assem2/meshes/Part_1_2.stl
0.01 x 0.01 x 0.01

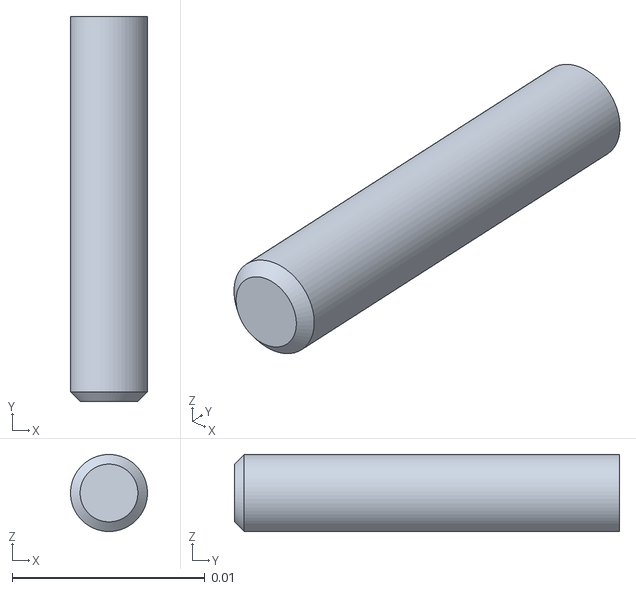
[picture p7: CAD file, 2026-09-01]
pochi_rl/pkg_4leg_assem2/meshes/Part_1.stl
0.00399 x 0.02 x 0.004

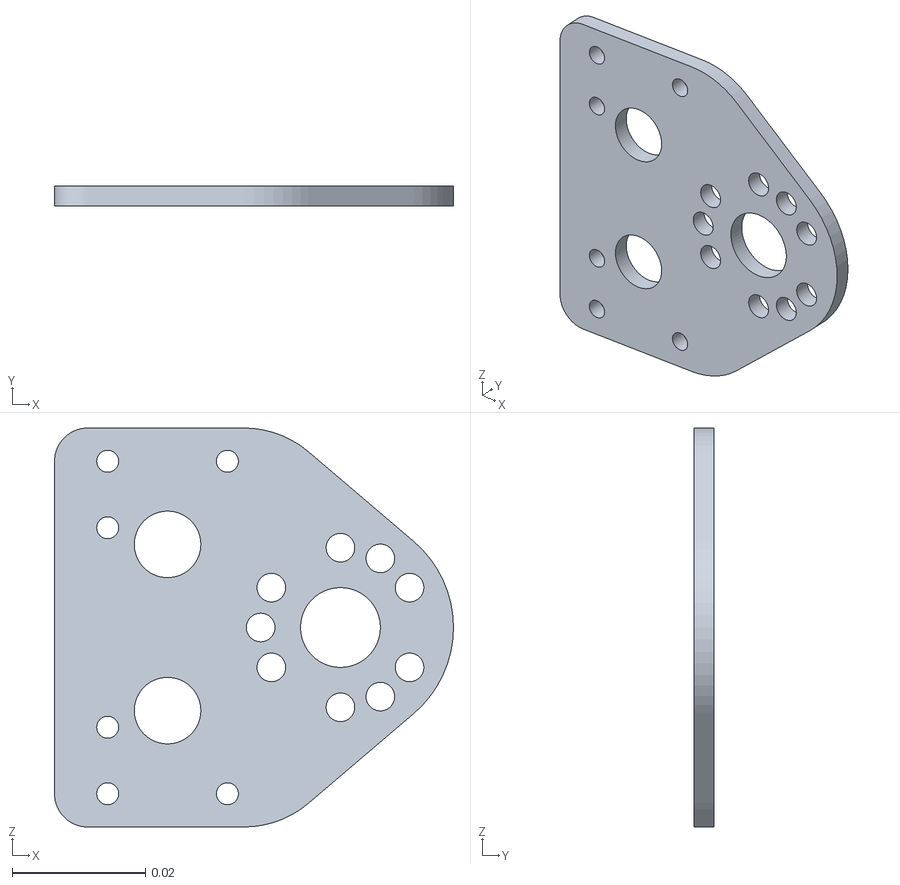
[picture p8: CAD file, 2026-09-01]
pochi_rl/pkg_4leg_assem2/meshes/carbon_plate_hip_1_2__3mm_x4_.stl
0.06 x 0.003 x 0.06

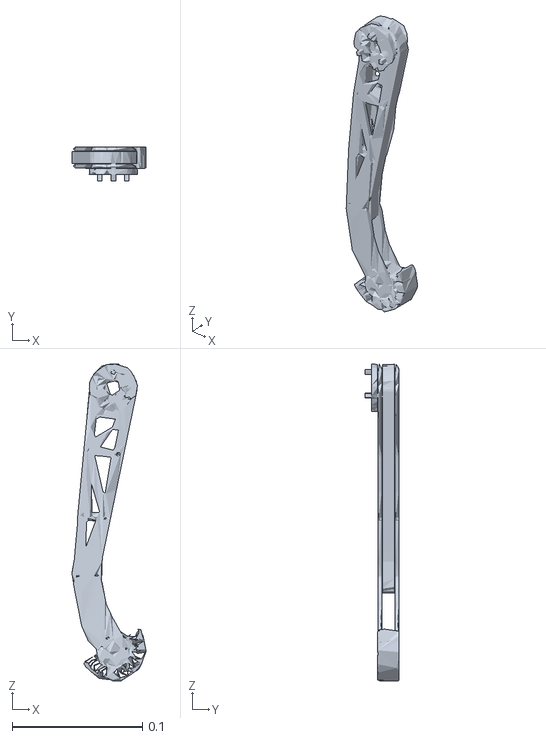
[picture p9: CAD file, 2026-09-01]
pochi_rl/assets/pochi/meshes/RL_shank.obj
0.0569 x 0.026 x 0.243

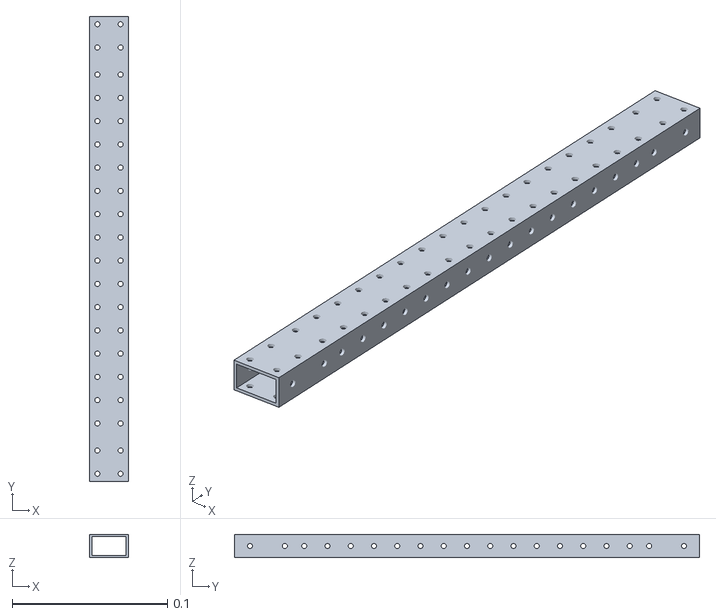
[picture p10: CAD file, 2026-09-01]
pochi_rl/pkg_4leg_assem2/meshes/Body_pipe2_y__25_15_1_5_300_x4_.stl
0.025 x 0.3 x 0.015

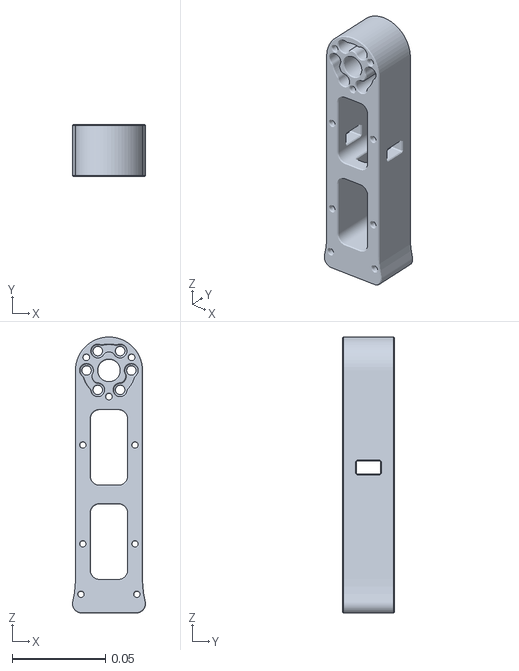
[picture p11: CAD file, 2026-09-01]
pochi_rl/pkg_4leg_assem2/meshes/Part_1_1.stl
0.0392 x 0.028 x 0.148

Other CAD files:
pochi_rl/assets/pochi/meshes/FR_hip.obj
pochi_rl/assets/pochi/meshes/RR_thigh.obj
pochi_rl/assets/pochi/meshes/FR_foot_pad.obj
pochi_rl/assets/pochi/meshes/FL_thigh.obj
pochi_rl/assets/pochi/meshes/FR_thigh.obj
pochi_rl/assets/pochi/meshes/FR_shank.obj
pochi_rl/assets/pochi/meshes/RR_shank.obj
pochi_rl/assets/pochi/meshes/FL_foot_pad.obj
pochi_rl/assets/pochi/meshes/FL_hip.obj
pochi_rl/assets/pochi/meshes/FL_shank.obj
pochi_rl/assets/pochi/meshes/RR_foot_pad.obj
pochi_rl/assets/pochi/meshes/RR_hip.obj
pochi_rl/assets/pochi/meshes/base_link.obj
pochi_rl/pkg_4leg_assem2/meshes/Body_pipe1_2_x__25_15_1_5_134_x4_.stl
pochi_rl/pkg_4leg_assem2/meshes/Body_pipe3_2_z__15_15_1_5_112_x4_.stl
pochi_rl/pkg_4leg_assem2/meshes/M3_10mm.stl
pochi_rl/pkg_4leg_assem2/meshes/M3_20mm.stl
pochi_rl/pkg_4leg_assem2/meshes/M3_25mm.stl
pochi_rl/pkg_4leg_assem2/meshes/M3_35mm.stl
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

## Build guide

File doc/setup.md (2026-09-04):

# 環境

- python 仮想環境 uv
- GPU CUDA 13.0

## docker の環境構築手順 (Jetson Orin Nano デバッグ環境)

```
docker compose build
```

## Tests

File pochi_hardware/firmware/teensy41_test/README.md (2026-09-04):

# Teensy 4.1 PlatformIO test

Teensy 4.1のPlatformIO環境とCAN3上のRoboStride 03を確認するためのプロジェクトです。

- CAN3: Classic CAN、1 Mbps
- RoboStride 03: CAN ID 0〜11
- マスターID: `0xFD`
- 制御方式: MIT control
- 起動時の既定状態: 全モーター停止
- USB Serial: 115200 bps
- USB packet: COBS + `0x00` delimiter + CRC-32
- LED: 12台のencoderが見えている間は点灯、不足時は点滅

起動時は12台すべてにStopを送り、MIT modeを設定したうえでencoderの読み取りを開始します。トルクはWebから明示的にONにするまで入りません。

## Joint reference pose

`src/can3.h` の `CAN3_INITIAL_POSITION_RAD` が、CAN ID `0..11` に対応する
負荷側absolute encoderの初期姿勢です。外部へ送る角度と外部から受けるMIT目標角度は、
`normalizeAngle(raw - initial)` により初期姿勢を `0 rad` とする `[-pi, pi]` の値です。
生encoder座標との相互変換は `src/robostride.h` 内で行います。

MIT位置目標は `src/can3.h` の `CAN3_MIN_POSITION_RAD` と
`CAN3_MAX_POSITION_RAD` でID別に制限されます。モーター取り付け方向による符号反転は
Webの3D描画だけに適用され、Mechanical positionとMIT目標値はTeensy座標のままです。

## Build

```bash
cd ~/Documents/GitHub/Pochi/pochi_hardware/firmware/teensy41_test
~/.platformio/penv/bin/pio run
```

## Upload

Teensy 4.1をUSBで接続して実行します。自動書き込みが始まらない場合は、基板上のProgramボタンを1回押します。

```bash
~/.platformio/penv/bin/pio run -t upload
```

## Change a RoboStride CAN ID

`test/change_id.cpp` is a one-shot ID changer for one RS03 using the private
29-bit CAN protocol. Edit `kOldMotorId` and `kNewMotorId`, temporarily use the
file as `src/main.cpp`, then build and upload it. Connect exactly one target
motor while changing an ID.

The program first scans every valid private-protocol device ID from `0x01`
through `0xFE` on CAN3 and prints
each responding ID. It then verifies the old ID, refuses to proceed if the new
ID already responds, disables the motor, changes the ID, and verifies both that
the new ID responds and the old ID no longer responds. A pass leaves the Teensy
LED on; a failure blinks it. After changing the ID, the program sends the Type
22 motor-data-save frame (`01 02 03 04 05 06 07 08`) to persist the setting.
Power-cycle the motor and scan again to verify persistence.

After changing all IDs, restore the normal `src/main.cpp` before uploading the
control firmware.

The normal firmware implements MIT-style operation control using RoboStride's
private extended-frame protocol (`run_mode = 0`). Do not switch the motor to the
separate standard-frame MIT communication protocol. If that protocol was
selected previously, switch the motor back to the private protocol and power
cycle it first.

## USB / UDP

The Teensy built-in LED stays off without valid host commands and blinks at
20 Hz while valid command packets are arriving from the Orin. This indicates
host communication only; it does not indicate that motor torque is enabled.

Motor control uses a latched safety state. At boot, after a host-command
timeout, or when any RoboStride response is stale for 250 ms, the Teensy stops
all 12 motors and returns to non-blocking initialization. All motors must stay
responsive for 500 ms before the state becomes READY. Recovery never restores
torque automatically: the Teensy must receive an all-disabled command followed
by a fresh all-enabled command from the web UI. Enabling starts from the live
joint pose.

The command packet carries an independent Enable bit for every motor. The web
UI can request all motors or any subset, and unselected actuators remain in
`Reset` while their encoders are still sampled. Selected motors are enabled in
CAN-ID order, one at a time. An unconfirmed actuator receives another Enable
request every 50 ms, up to 20 attempts. After it answers with motor mode `Run`,
its captured-position MIT command becomes active and the firmware waits 500 ms
before starting the next selected actuator. A missing confirmation after 20
attempts or a later return to `Reset` stops every motor and latches another
re-arm request. The web UI reports `ENABLE PENDING`, `RESET`, `CALIBRATION`, and
`RUN` from actuator feedback rather than from the outgoing command alone.

Immediately before each Enable sequence, the Teensy captures that actuator's
latest encoder position and sends it as an MIT goal. It sends the same goal
again immediately after every Enable request and holds it for the first 100 ms
after the `Run` reply. This prevents a target retained by the actuator from a
previous run from moving the joint during startup.

Joint targets are converted back to the raw MIT coordinate using the `2pi`
equivalent angle nearest to the latest raw encoder reading. A plain
`offset + joint` conversion can cross the absolute-encoder wrap and request a
position one full revolution away while still appearing numerically valid in
the RS03 `[-4pi, 4pi]` MIT range.

```bash
cd ~/Documents/GitHub/Pochi
uv sync
uv run python pochi_hardware/src/teensy_usb_test.py --serial /dev/ttyACM0
```

USBとUDPを中継する場合は次を実行します。UDP commandはport 15000で受信し、stateはport 15001へ送信します。

```bash
uv run python pochi_hardware/src/teensy_udp_bridge.py \
  --serial /dev/ttyACM0 \
  --command-bind 0.0.0.0:15000 \
  --state-dest 127.0.0.1:15001
```

## Protocol

- Python → Teensy: 12台分のMIT指令を1個の316-byte packetで送信
- Teensy → Python: 12台分の状態とIMUを1個の860-byte packetで返信
- USB上ではCOBS encode後に`0x00`を付加
- UDP上ではCOBSを外したpacketを1 datagramとして送受信
- 指令が50 ms途絶えると全モーターを停止
- CRC、sequence、motor ID、有限値を検査してから12台分を一括更新

IMUはcore2025 upperと同じICM-20948を使用し、SPI1のMOSI 26、MISO 39、SCK 27、CS 38へ接続します。

## Test

```bash
cd ~/Documents/GitHub/Pochi
uv run pytest -q
```

実機に対して全モーターDisableのままUSB/UDP往復を確認する場合は、ブリッジを起動した別ターミナルから実行します。

```bash
uv run python pochi_hardware/src/teensy_udp_test.py --duration 3
```

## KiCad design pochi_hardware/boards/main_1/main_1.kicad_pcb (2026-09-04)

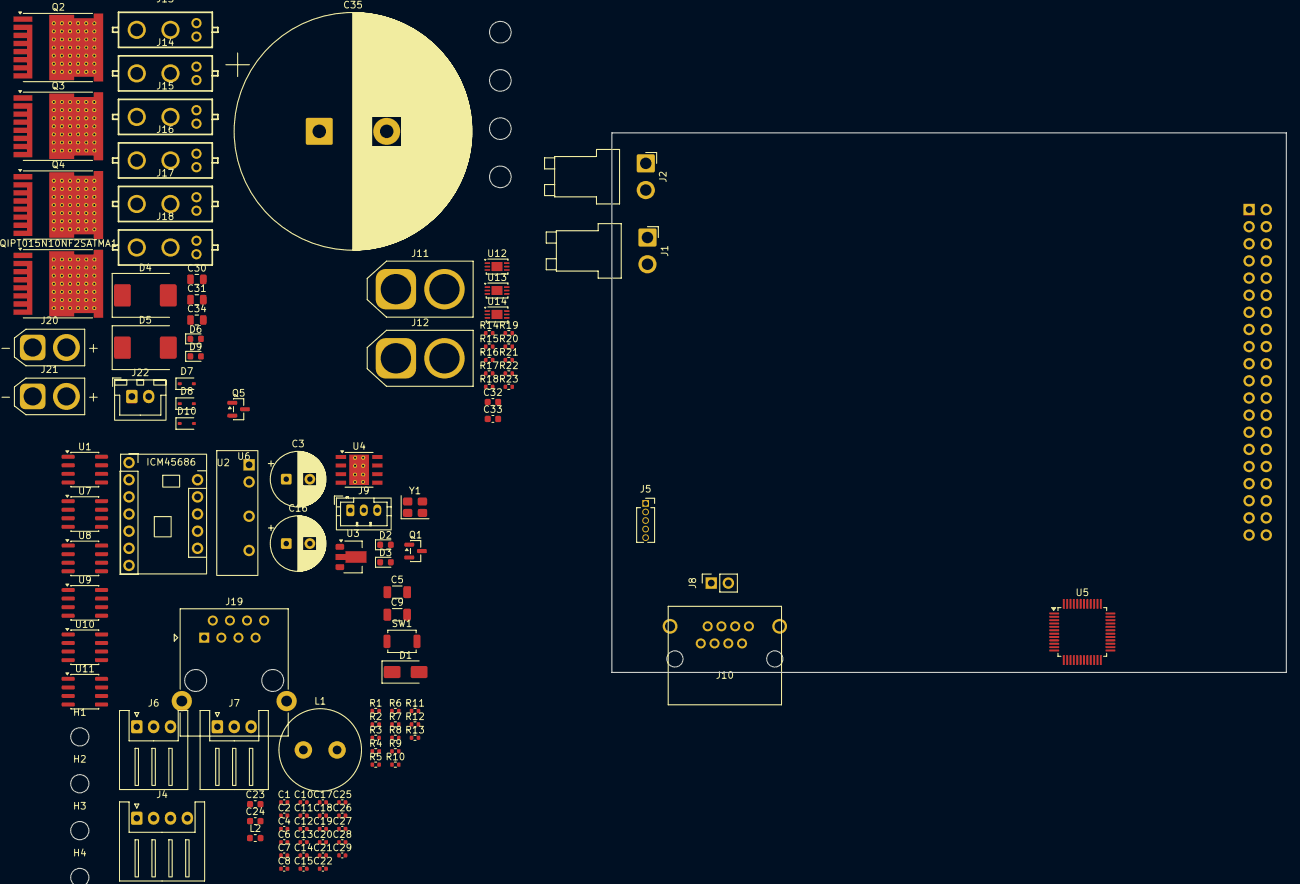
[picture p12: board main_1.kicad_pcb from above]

Board: 2 copper layers, 100.0 x 80.0 mm, 122 parts (1 on the bottom side), 83 nets, no tracks yet.

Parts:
C1, C19, C20, C21, C22, C25, C26, C27, C28: 100n; C_0402_1005Metric
C2: 4.7u/16V; C_0402_1005Metric
C3, C16: 220u; CP_Radial_D8.0mm_P3.50mm
C4: 10u/0603/25V; C_0402_1005Metric
C5, C9: 4.7u; C_1206_3216Metric
C6, C7, C10, C13, C15: 100n/16V; C_0402_1005Metric
C8, C11: 10p/50V; C_0402_1005Metric
C12: 10u/0402/6.3V; C_0402_1005Metric
C14: 0.01u; C_0402_1005Metric
C17: 10n/50V; C_0402_1005Metric
C18: 1u/25V; C_0402_1005Metric
C23: 2.2u; C_0603_1608Metric
C24: 1u; C_0603_1608Metric
C29: 0.1u; C_0402_1005Metric
C30, C31, C34: 1.5u; C_0805_2012Metric
C32, C33: 10n; C_0603_1608Metric
C35: 10000u/50V; CP_Radial_D35.0mm_P10.00mm_SnapIn
D1: SS34; D_SMA
D2, D6: Green; LED_0603_1608Metric
D3: Yello; LED_0603_1608Metric
D4, D5: SMDJ48A; D_SMC
D7, D8, D10: IPT015N10NF2SATMA1; D_SOD-323
D9: RED; LED_0603_1608Metric
H1, H2, H3, H4: MountingHole; MountingHole_2.7mm_M2.5
H5, H6, H7, H8: MountingHole; MountingHole_3.2mm_M3_DIN965
J1, J2: VH; JST_VH_B2PS-VH_1x02_P3.96mm_Horizontal
J3: Conn_02x20_Odd_Even; PinSocket_2x20_P2.54mm_Vertical
J4: RS485; JST_XH_S4B-XH-A_1x04_P2.50mm_Horizontal
J5: Pad; PinSocket_1x05_P1.27mm_Vertical
J6, J7: XH; JST_XH_S3B-XH-A_1x03_P2.50mm_Horizontal
J8: DIP; PinSocket_1x02_P2.54mm_Vertical
J9: PH; JST_PH_B3B-PH-K_1x03_P2.00mm_Vertical
J10: RJ45; 7810-8P8C
J11, J12: XT60-M; AMASS_XT60-M_1x02_P7.20mm_Vertical
J13, J14, J15, J16, J17, J18: XT30(2+2)-M; CONN-TH_XT30PB-M
J19: RJ45; RJ45_Ninigi_GE
J20, J21: XT30; AMASS_XT30U-F_1x02_P5.0mm_Vertical
J22: XH; JST_XH_B2B-XH-A_1x02_P2.50mm_Vertical
L1: 22u; L_Radial_D12.0mm_P5.00mm_Fastron_11P
L2: 600Ω; L_0603_1608Metric
Q1: S9012; SOT-23
Q2, Q3, Q4: IPT015N10NF2SATMA1; Infineon_PG-HSOF-8-1_ThermalVias
Q5: 2N7002; SOT-23
QIPT015N10NF2SATMA1: NMOS; Infineon_PG-HSOF-8-1_ThermalVias
R1, R7, R8, R9: 120; R_0402_1005Metric
R2, R3, R18: 10k; R_0402_1005Metric
R4: 3.24k; R_0402_1005Metric
R5, R6: 47K; R_0402_1005Metric
R10: 7.5k; R_0402_1005Metric
R11: 20k; R_0402_1005Metric
R12, R13: 2.2k; R_0402_1005Metric
R14, R15: 47k; R_0402_1005Metric
R16, R17, R20: 1k; R_0402_1005Metric
R19: 10; R_0402_1005Metric
R21, R22: 15k; R_0402_1005Metric
R23: 4.7k; R_0402_1005Metric
SW1: RESET; SW_SPST_TS-1088-xR020
U1: SP3485EN; SOIC-8_3.9x4.9mm_P1.27mm
U2: ICM45686
U3: HT7533-1; SOT-89-3
U4: TPS5430DDA; TI_SO-PowerPAD-8_ThermalVias
U5: STM32G474CBTx; LQFP-48_7x7mm_P0.5mm
U6: MAU102
U7, U8, U9: ISO1044BD; SOIC-8_3.9x4.9mm_P1.27mm
U10: ADuM121N; SOIC-8_3.9x4.9mm_P1.27mm
U11: SP485E; SOIC-8_3.9x4.9mm_P1.27mm
U12, U13, U14: LTC4359-DCB; DFN-6-1EP_3x2mm_P0.5mm_EP1.65x1.35mm
Y1: 16MHz/9p; Crystal_SMD_3225-4Pin_3.2x2.5mm

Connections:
+3V3: C1.1, C2.1, C6.1, C10.1, C12.1, C13.1, C15.1, C19.1, C20.1, C21.1, C22.1, J5.2, L2.2, U1.8 (VCC), U2.2 (3V3), U3.3 (VO), U5.1 (VBAT), U5.20 (VREF+), U5.24 (VDD), U5.36 (VDD), U5.48 (VDD), U7.1 (VCC1), U8.1 (VCC1), U9.1 (VCC1), U10.1 (VDD1)
+5V: C4.1, C16.1, C23.1, J4.2, J6.2, J7.2, L1.2, R3.1, U3.2 (VI), U6.1 (+Vin)
+5VP: C24.1, C25.1, C26.1, C27.1, C28.1, C29.1, Q1.3 (C), R12.1, U6.6 (+Vout), U7.8 (VCC2), U8.8 (VCC2), U9.8 (VCC2), U10.8 (VDD2), U11.8 (VCC)
+48V: C30.1, J20.2, J21.2, Q2.1 (D), Q4.1 (D), R14.1, R21.1, U12.1 (OUT), U13.1 (OUT), U14.4 (IN)
/MCU/19V: C3.1, C5.1, C9.1, J1.2, J2.2, J8.1, R5.1, U4.7 (VIN)
/MCU/BOOT0: J3.27, R2.1, U5.45 (PB8)
/MCU/CAN1_H: J10.1, R7.1, U7.6 (CANH)
/MCU/CAN1_L: J10.2, R7.2, U7.5 (CANL)
/MCU/CAN1_RX: U5.33 (PA11), U7.3 (RXD)
/MCU/CAN1_TX: U5.46 (PB9), U7.2 (TXD)
/MCU/CAN2_H: J10.7, R8.1, U8.6 (CANH)
/MCU/CAN2_L: J10.8, R8.2, U8.5 (CANL)
/MCU/CAN2_RX: U5.42 (PB5), U8.3 (RXD)
/MCU/CAN2_TX: U5.43 (PB6), U8.2 (TXD)
/MCU/CAN3_H: J10.4, R9.1, U9.6 (CANH)
/MCU/CAN3_L: J10.5, R9.2, U9.5 (CANL)
/MCU/CAN3_RX: U5.40 (PB3), U9.3 (RXD)
/MCU/CAN3_TX: U5.41 (PB4), U9.2 (TXD)
/MCU/JTAG_RX: J3.8, U5.11 (PA3)
/MCU/JTAG_TX: J3.10, U5.10 (PA2)
/MCU/LED_MCU: R6.1, U5.18 (PB2)
/MCU/LED_PWM1: J6.3, U5.39 (PA15)
/MCU/LED_PWM2: J7.3, U5.9 (PA1)
/MCU/NRST: C7.2, J3.12, J3.29, J5.5, SW1.1, U5.7 (PG10)
/MCU/RS485_A: J4.3, R1.1, U1.6 (A)
/MCU/RS485_B: J4.4, R1.2, U1.7 (B)
/MCU/RS485_DE: U1.2 (~RE), U1.3 (DE), U5.34 (PA12)
/MCU/RS485_RX: U1.1 (RO), U5.32 (PA10)
/MCU/RS485_TX: U1.4 (DI), U5.31 (PA9)
/MCU/SPI_Master_INT: U2.10 (INT1), U5.30 (PA8)
/MCU/SPI_Master_MISO: U2.7 (MISO), U5.28 (PB14)
/MCU/SPI_Master_MOSI: U2.5 (MOSI), U5.29 (PB15)
/MCU/SPI_Master_NSS: U2.6 (CS), U5.26 (PB12)
/MCU/SPI_Master_SCK: U2.4 (SCK), U5.27 (PB13)
/MCU/SPI_Slave_MISO: J3.22, U5.14 (PA6)
/MCU/SPI_Slave_MOSI: J3.21, U5.15 (PA7)
/MCU/SPI_Slave_NSS: J3.24, U5.12 (PA4)
/MCU/SPI_Slave_SCK: J3.23, U5.13 (PA5)
/MCU/SWCLK: J5.3, U5.38 (PA14)
/MCU/SWDIO: J5.4, U5.37 (PA13)
/MCU/UART_RX_OUT: U10.7 (VIA), U11.1 (RO)
/MCU/UART_TTL: J9.3, U11.6 (A)
/MCU/UART_TX_OUT: R10.1, U10.6 (VOB), U11.4 (DI)
/Power/48V1: D4.1 (A1), D8.2 (A), J11.2, Q3.3 (S), U13.3 (SRC), U13.4 (IN)
/Power/48V2: D5.1 (A1), D7.2 (A), J12.2, Q2.3 (S), U12.3 (SRC), U12.4 (IN)
/Power/CAN1_H: J13.2, J14.2, J19.1
/Power/CAN1_L: J13.1, J14.1, J19.2
/Power/CAN2_H: J15.2, J16.2, J19.7
/Power/CAN2_L: J15.1, J16.1, J19.8
/Power/CAN3_H: J17.2, J18.2, J19.4
/Power/CAN3_L: J17.1, J18.1, J19.5
/Power/MotorPWR: C34.1, C35.1, J13.4, J14.4, J15.4, J16.4, J17.4, J18.4, QIPT015N10NF2SATMA1.1 (D), R15.1, U14.1 (OUT)
/Power/SHDN: C33.2, Q5.3 (D), U14.5 (~SHDN)
GND: C1.2, C2.2, C3.2, C4.2, C5.2, C6.2, C7.1, C8.2, C9.2, C10.2, C11.2, C12.2, C13.2, C15.2, C16.2, C17.2, C18.2, C19.2, C20.2, C21.2, C22.2, C23.2, D1.2 (A), D2.1 (K), D3.1 (K), J1.1, J2.1, J3.6, J3.9, J3.14, J3.20, J3.25, J3.30, J3.34, J3.39, J4.1, J5.1, J6.1, J7.1, J8.2, R2.2, R4.2, SW1.2, U1.5 (GND), U2.3 (GND), U3.1 (GND), U4.6 (GND), U4.9 (GNDPAD), U5.19 (VSSA), U5.23 (VSS), U5.35 (VSS), U5.47 (VSS), U6.2 (-Vin), U7.4 (GND1), U8.4 (GND1), U9.4 (GND1), U10.4 (GND1), Y1.2, Y1.4
GNDD: C24.2, C25.2, C26.2, C27.2, C28.2, C29.2, J9.1, J10.6, R11.2, R13.2, U6.4 (-Vout), U7.7 (GND2), U8.7 (GND2), U9.7 (GND2), U10.5 (GND2), U11.5 (GND)
GNDPWR: C32.1, C33.1, C35.2, D6.1 (K), D9.1 (K), J13.3, J14.3, J15.3, J16.3, J17.3, J18.3, J19.6, J20.1, J21.1, J22.1, Q5.2 (S), R16.2, R17.2, R20.2, R23.2
unnamed: C32.2, R18.1
unnamed: C14.2, D1.1 (K), L1.1, U4.8 (PH)
unnamed: D2.2 (A), R5.2
unnamed: D3.2 (A), R6.2
unnamed: D4.2 (A2), J11.1
unnamed: D5.2 (A2), J12.1
unnamed: D6.2 (A), R14.2
unnamed: D7.1 (K), Q2.2 (G), U12.2 (GATE)
unnamed: D8.1 (K), Q3.2 (G), U13.2 (GATE)
unnamed: D9.2 (A), R15.2
unnamed: D10.2 (A), Q4.3 (S), QIPT015N10NF2SATMA1.3 (S), U14.3 (SRC)
unnamed: D10.1 (K), QIPT015N10NF2SATMA1.2 (G), R18.2, R19.1, U14.2 (GATE)
unnamed: J22.2, Q5.1 (G), R22.2, R23.1
unnamed: Q1.1 (B), R10.2
unnamed: Q1.2 (E), R11.1, U11.2 (~RE), U11.3 (DE)
unnamed: C31.1, Q3.1 (D)
unnamed: Q4.2 (G), R19.2
unnamed: R21.2, R22.1
unnamed: C14.1, U4.1 (BOOT)
unnamed: R3.2, R4.1, U4.4 (VSENSE)
unnamed: C8.1, U5.5 (PF0), Y1.1
unnamed: C11.1, U5.6 (PF1), Y1.3
unnamed: C17.1, C18.1, L2.1, U5.21 (VDDA)
unnamed: R12.2, R13.1, U11.7 (B)
unnamed: C30.2, R16.1, U12.6 (Vss), U12.7 (Pad)
unnamed: C31.2, R17.1, U13.6 (Vss), U13.7 (Pad)
unnamed: C34.2, R20.1, U14.6 (Vss), U14.7 (Pad)

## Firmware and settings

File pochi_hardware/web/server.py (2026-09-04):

#!/usr/bin/env python3
from __future__ import annotations

import argparse
import asyncio
import contextlib
import math
import threading
import time
from collections.abc import AsyncIterator

import uvicorn
from fastapi import FastAPI, WebSocket, WebSocketDisconnect
from fastapi.responses import JSONResponse

from pochi_client import (
    COMMAND_ENABLE,
    CONTROL_MIT,
    JOINTS,
    JOINT_BY_ID,
    STATE_CAN_INITIALIZING,
    STATE_CAN_READY,
    STATE_REARM_REQUIRED,
    STATE_TORQUE_ACTIVE,
    MotorCommand,
    PochiClient,
)

MOTOR_INITIALIZED = 1 << 0
MOTOR_CONNECTED = 1 << 1
MOTOR_FEEDBACK_VALID = 1 << 2
MOTOR_ENABLE_REQUESTED = 1 << 3
MOTOR_FAULT = 1 << 6
MOTOR_ENABLE_PENDING = 1 << 7
MOTOR_MODE_RUN = 2
IMU_INITIALIZED = 1 << 0
IMU_SAMPLE_VALID = 1 << 1

JOINT_LIMITS_RAD = {
    "hip": (math.radians(-40.0), math.pi / 2.0),
    "thigh": (-math.pi / 2.0, math.pi / 2.0),
    "calf": (-3.0 * math.pi / 4.0, 3.0 * math.pi / 4.0),
}


def _finite(value: float) -> float | None:
    return value if math.isfinite(value) else None


def _motor_mode_text(status: int) -> str:
    return {0: "RESET", 1: "CALIBRATION", 2: "RUN"}.get(status, "UNKNOWN")


def _motor_state_text(flags: int, fault_code: int, status: int) -> str:
    if flags & MOTOR_FAULT:
        return f"FAULT {fault_code}"
    if flags & MOTOR_ENABLE_PENDING:
        return f"ENABLE PENDING ({_motor_mode_text(status)})"
    if flags & MOTOR_ENABLE_REQUESTED:
        return "MIT RUN" if status == 2 else f"MODE {_motor_mode_text(status)}"
    if flags & MOTOR_CONNECTED:
        return "ENCODER LIVE"
    if flags & MOTOR_FEEDBACK_VALID:
        return "STALE"
    if flags & MOTOR_INITIALIZED:
        return "NO RESPONSE"
    return "NOT INITIALIZED"


def _quaternion_to_rpy_deg(w: float, x: float, y: float, z: float) -> tuple[float | None, ...]:
    if not all(math.isfinite(value) for value in (w, x, y, z)):
        return None, None, None
    roll = math.atan2(2.0 * (w * x + y * z), 1.0 - 2.0 * (x * x + y * y))
    pitch = math.asin(max(-1.0, min(1.0, 2.0 * (w * y - z * x))))
    yaw = math.atan2(2.0 * (w * z + x * y), 1.0 - 2.0 * (y * y + z * z))
    return tuple(math.degrees(value) for value in (roll, pitch, yaw))


class WebControlService:
    """Own the browser control state and keep torque off until explicit opt-in."""

    def __init__(self, client: PochiClient, *, kp: float = 40.0, kd: float = 1.0) -> None:
        self.client = client
        self.kp = kp
        self.kd = kd
        self.torque_enabled = False
        self._requested_motor_ids: set[int] = set()
        self.emergency_stop = False
        self._enable_pending_until = 0.0
        self._firmware_active_seen = False
        self._firmware_arm_accepted = False
        self.browser_count = 0
        self._targets = {joint.motor_id: 0.0 for joint in JOINTS}
        self._lock = threading.Lock()

    def register_browser(self) -> None:
        with self._lock:
            self.browser_count += 1

    def unregister_browser(self) -> None:
        with self._lock:
            self.browser_count = max(0, self.browser_count - 1)
            should_disable = self.browser_count == 0
        if should_disable:
            self.disable_all()

    def unavailable_motor_ids(self, motor_ids: set[int] | None = None) -> list[int]:
        state = self.client.latest_state()
        selected_ids = set(JOINT_BY_ID) if motor_ids is None else motor_ids
        if state is None:
            return sorted(selected_ids)
        by_id = {motor.motor_id: motor for motor in state.motors}
        return [
            joint.motor_id
            for joint in JOINTS
            if joint.motor_id in selected_ids
            if (motor := by_id.get(joint.motor_id)) is None
            or not math.isfinite(motor.position_rad)
            or not (motor.flags & MOTOR_CONNECTED)
            or bool(motor.flags & MOTOR_FAULT)
            or not (
                JOINT_LIMITS_RAD[joint.joint][0]
                <= motor.position_rad
                <= JOINT_LIMITS_RAD[joint.joint][1]
            )
        ]

    def enable_all(self) -> None:
        state = self.client.latest_state()
        if state is None or not (state.header.flags & STATE_CAN_READY):
            raise ValueError("Teensy is still initializing; wait for READY before enabling torque")
        unavailable = self.unavailable_motor_ids()
        if unavailable:
            joined = ", ".join(map(str, unavailable))
            raise ValueError(f"valid feedback is required from all motors; unavailable IDs: {joined}")

        by_id = {motor.motor_id: motor for motor in state.motors}
        commands: list[MotorCommand] = []
        targets: dict[int, float] = {}
        for joint in JOINTS:
            motor = by_id[joint.motor_id]
            targets[joint.motor_id] = motor.position_rad
            commands.append(
                MotorCommand(
                    motor_id=joint.motor_id,
                    control_mode=CONTROL_MIT,
                    flags=COMMAND_ENABLE,
                    position_rad=motor.position_rad,
                    velocity_rad_s=0.0,
                    kp=self.kp,
                    kd=self.kd,
                    torque_nm=0.0,
                )
            )

        with self._lock:
            self.client.clear_emergency_stop()
            self.client.set_all_mit(commands)
            self._targets = targets
            self._requested_motor_ids = set(JOINT_BY_ID)
            self.emergency_stop = False
            self.torque_enabled = True
            self._enable_pending_until = time.monotonic() + 1.0
            self._firmware_active_seen = False
            self._firmware_arm_accepted = False

    def disable_all(self) -> None:
        with self._lock:
            self.client.disable_all()
            self.torque_enabled = False
            self._requested_motor_ids.clear()
            self._enable_pending_until = 0.0
            self._firmware_active_seen = False
            self._firmware_arm_accepted = False

    def set_motor_enabled(self, motor_id: int, enabled: bool) -> None:
        if isinstance(motor_id, bool) or motor_id not in JOINT_BY_ID:
            raise ValueError("motorId must be an integer from 0 through 11")

        if not enabled:
            with self._lock:
                self.client.disable(motor_id)
                self._requested_motor_ids.discard(motor_id)
                self.torque_enabled = bool(self._requested_motor_ids)
                if not self.torque_enabled:
                    self._enable_pending_until = 0.0
                    self._firmware_active_seen = False
                    self._firmware_arm_accepted = False
            return

        state = self.client.latest_state()
        if state is None or not (state.header.flags & STATE_CAN_READY):
            raise ValueError("Teensy is still initializing; wait for READY before enabling torque")
        unavailable = self.unavailable_motor_ids({motor_id})
        if unavailable:
            raise ValueError(f"valid feedback is required from motor ID {motor_id}")
        motor = next(motor for motor in state.motors if motor.motor_id == motor_id)

        with self._lock:
            self.client.clear_emergency_stop()
            self._targets[motor_id] = motor.position_rad
            self.client.set_mit(
                motor_id,
                position_rad=motor.position_rad,
                velocity_rad_s=0.0,
                kp=self.kp,
                kd=self.kd,
                torque_nm=0.0,
                enable=True,
            )
            self._requested_motor_ids.add(motor_id)
            self.torque_enabled = True
            self.emergency_stop = False
            self._enable_pending_until = time.monotonic() + 1.5

    def set_target(self, motor_id: int, display_position_rad: float) -> None:
        if isinstance(motor_id, bool) or motor_id not in JOINT_BY_ID:
            raise ValueError("motorId must be an integer from 0 through 11")
        if not math.isfinite(display_position_rad):
            raise ValueError("positionRad must be finite")
        joint = JOINT_BY_ID[motor_id]
        low, high = JOINT_LIMITS_RAD[joint.joint]
        clamped = max(low, min(high, display_position_rad))
        with self._lock:
            self._targets[motor_id] = clamped
            if motor_id in self._requested_motor_ids:
                self.client.set_mit(
                    motor_id,
                    position_rad=clamped,
                    velocity_rad_s=0.0,
                    kp=self.kp,
                    kd=self.kd,
                    torque_nm=0.0,
                    enable=True,
                )

    def set_gains(self, kp: float, kd: float) -> None:
        if not math.isfinite(kp) or not 0.0 <= kp <= 5000.0:
            raise ValueError("gains.kp must be finite and between 0 and 5000")
        if not math.isfinite(kd) or not 0.0 <= kd <= 100.0:
            raise ValueError("gains.kd must be finite and between 0 and 100")

        with self._lock:
            self.kp = kp
            self.kd = kd
            for motor_id in sorted(self._requested_motor_ids):
                self.client.set_mit(
                    motor_id,
                    position_rad=self._targets[motor_id],
                    velocity_rad_s=0.0,
                    kp=self.kp,
                    kd=self.kd,
                    torque_nm=0.0,
                    enable=True,
                )

    def zero_all_targets(self) -> None:
        with self._lock:
            for motor_id in self._targets:
                self._targets[motor_id] = 0.0
            for motor_id in sorted(self._requested_motor_ids):
                self.client.set_mit(
                    motor_id,
                    position_rad=0.0,
                    velocity_rad_s=0.0,
                    kp=self.kp,
                    kd=self.kd,
                    torque_nm=0.0,
                    enable=True,
                )

    def emergency_stop_all(self) -> None:
        with self._lock:
            self.client.emergency_stop()
            self.emergency_stop = True
            self.torque_enabled = False
            self._requested_motor_ids.clear()
            self._enable_pending_until = 0.0
            self._firmware_active_seen = False
            self._firmware_arm_accepted = False

    def _sync_firmware_safety(self, state: object | None) -> None:
        if state is None:
            return
        header = getattr(state, "header", None)
        flags = getattr(header, "flags", 0)
        firmware_active = bool(flags & STATE_TORQUE_ACTIVE)
        rearm_required = bool(flags & STATE_REARM_REQUIRED)
        should_disable = False
        pending_target_updates: list[tuple[int, float]] = []
        with self._lock:
            if self.torque_enabled and not rearm_required:
                self._firmware_arm_accepted = True
            if firmware_active:
                self._firmware_active_seen = True
                self._enable_pending_until = 0.0
            elif self.torque_enabled and rearm_required:
                enable_timed_out = (
                    self._enable_pending_until > 0.0
                    and time.monotonic() >= self._enable_pending_until
                )
                if (
                    self._firmware_active_seen
                    or self._firmware_arm_accepted
                    or enable_timed_out
                ):
                    self.torque_enabled = False
                    self._requested_motor_ids.clear()
                    self._enable_pending_until = 0.0
                    self._firmware_active_seen = False
                    self._firmware_arm_accepted = False
                    should_disable = True
            if self.torque_enabled and not firmware_active and not should_disable:
                # Staggered arming takes several seconds. Pending motors must
                # follow their latest passive pose instead of moving toward
                # the stale pose captured when ON was first pressed.
                for motor in getattr(state, "motors", []):
                    if (
                        motor.motor_id in self._requested_motor_ids
                        and motor.status != MOTOR_MODE_RUN
                        and math.isfinite(motor.position_rad)
                    ):
                        self._targets[motor.motor_id] = motor.position_rad
                        pending_target_updates.append(
                            (motor.motor_id, motor.position_rad)
                        )
        if should_disable:
            self.client.disable_all()
        else:
            for motor_id, position_rad in pending_target_updates:
                self.client.set_mit(
                    motor_id,
                    position_rad=position_rad,
                    velocity_rad_s=0.0,
                    kp=self.kp,
                    kd=self.kd,
                    torque_nm=0.0,
                    enable=True,
                )

    def handle_message(self, message: dict[str, object]) -> None:
        message_type = message.get("type")
        if message_type == "torque":
            enabled = message.get("enabled")
            if not isinstance(enabled, bool):
                raise ValueError("torque.enabled must be a boolean")
            self.enable_all() if enabled else self.disable_all()
            return
        if message_type == "motorTorque":
            motor_id = message.get("motorId")
            enabled = message.get("enabled")
            if isinstance(motor_id, bool) or not isinstance(motor_id, int):
                raise ValueError("motorTorque.motorId must be an integer")
            if not isinstance(enabled, bool):
                raise ValueError("motorTorque.enabled must be a boolean")
            self.set_motor_enabled(motor_id, enabled)
            return
        if message_type == "target":
            motor_id = message.get("motorId")
            position = message.get("positionRad")
            if isinstance(motor_id, bool) or not isinstance(motor_id, int):
                raise ValueError("target.motorId must be an integer")
            if isinstance(position, bool) or not isinstance(position, (int, float)):
                raise ValueError("target.positionRad must be a number")
            self.set_target(motor_id, float(position))
            return
        if message_type == "gains":
            kp = message.get("kp")
            kd = message.get("kd")
            if isinstance(kp, bool) or not isinstance(kp, (int, float)):
                raise ValueError("gains.kp must be a number")
            if isinstance(kd, bool) or not isinstance(kd, (int, float)):
                raise ValueError("gains.kd must be a number")
            self.set_gains(float(kp), float(kd))
            return
        if message_type == "zeroTargets":
            self.zero_all_targets()
            return
        if message_type == "emergencyStop":
            self.emergency_stop_all()
            return
        raise ValueError(f"unknown message type: {message_type!r}")

    def snapshot(self) -> dict[str, object]:
        state = self.client.latest_state()
        self._sync_firmware_safety(state)
        stats = self.client.stats()
        unavailable = self.unavailable_motor_ids()
        by_id = {motor.motor_id: motor for motor in state.motors} if state else {}
        motors: list[dict[str, object]] = []
        connected_count = 0
        active_torque_count = 0
        with self._lock:
            targets = dict(self._targets)
            requested_motor_ids = set(self._requested_motor_ids)
            torque_requested = bool(requested_motor_ids)
            emergency_stop = self.emergency_stop
            kp = self.kp
            kd = self.kd

        state_flags = state.header.flags if state is not None else 0
        firmware_initializing = bool(state_flags & STATE_CAN_INITIALIZING)
        firmware_ready = bool(state_flags & STATE_CAN_READY)
        rearm_required = bool(state_flags & STATE_REARM_REQUIRED)
        torque_active = bool(state_flags & STATE_TORQUE_ACTIVE)
        if state is None or not self.client.connected:
            safety_state = "NO DATA"
        elif firmware_initializing:
            safety_state = "INITIALIZING"
        elif torque_active:
            safety_state = "MIT ACTIVE"
        elif firmware_ready and rearm_required:
            safety_state = "READY / TORQUE OFF"
        elif firmware_ready:
            safety_state = "READY"
        else:
            safety_state = "WAITING FOR MOTORS"

        for joint in JOINTS:
            motor = by_id.get(joint.motor_id)
            if motor is None:
                motors.append(
                    {
                        "id": joint.motor_id,
                        "name": joint.name,
                        "label": joint.label,
                        "leg": joint.leg,
                        "joint": joint.joint,
                        "positionRad": None,
                        "positionDeg": None,
                        "velocityRadS": None,
                        "torqueNm": None,
                        "targetRad": targets[joint.motor_id],
                        "tempMosC": None,
                        "busVoltageV": None,
                        "ageMs": None,
                        "status": None,
                        "flags": 0,
                        "faultCode": 0,
                        "state": "NO DATA",
                        "torqueRequested": joint.motor_id in requested_motor_ids,
                        "torqueEnabled": False,
                        "canEnableTorque": False,
                    }
                )
                continue

            position = motor.position_rad
            position_value = _finite(position)
            connected = bool(motor.flags & MOTOR_CONNECTED) and position_value is not None
            connected_count += int(connected)
            motor_torque_enabled = bool(motor.flags & MOTOR_ENABLE_REQUESTED) and (
                motor.status == MOTOR_MODE_RUN
            )
            active_torque_count += int(motor_torque_enabled)
            low, high = JOINT_LIMITS_RAD[joint.joint]
            motor_can_enable = (
                firmware_ready
                and connected
                and not bool(motor.flags & MOTOR_FAULT)
                and position_value is not None
                and low <= position_value <= high
            )
            motors.append(
                {
                    "id": joint.motor_id,
                    "name": joint.name,
                    "label": joint.label,
                    "leg": joint.leg,
                    "joint": joint.joint,
                    "positionRad": position_value,
                    "positionDeg": None if position_value is None else math.degrees(position_value),
                    "velocityRadS": _finite(motor.velocity_rad_s),
                    "torqueNm": _finite(motor.torque_nm),
                    "targetRad": targets[joint.motor_id],
                    "tempMosC": _finite(motor.temp_mos_c),
                    "busVoltageV": _finite(motor.bus_voltage_v),
                    "ageMs": None
                    if motor.last_rx_age_us == 0xFFFFFFFF
                    else motor.last_rx_age_us / 1000.0,
                    "status": motor.status,
                    "flags": motor.flags,
                    "faultCode": motor.fault_code,
                    "state": _motor_state_text(
                        motor.flags, motor.fault_code, motor.status
                    ),
                    "torqueRequested": joint.motor_id in requested_motor_ids,
                    "torqueEnabled": motor_torque_enabled,
                    "canEnableTorque": motor_can_enable,
                }
            )

        imu_payload: dict[str, object] = {
            "connected": False,
            "rollDeg": None,
            "pitchDeg": None,
            "yawDeg": None,
            "quaternionW": None,
            "quaternionX": None,
            "quaternionY": None,
            "quaternionZ": None,
            "ageMs": None,
            "sampleCounter": 0,
            "accuracy": 0,
        }
        if state is not None:
            imu = state.imu
            quaternion = (
                imu.quaternion_w,
                imu.quaternion_x,
                imu.quaternion_y,
                imu.quaternion_z,
            )
            roll, pitch, yaw = _quaternion_to_rpy_deg(*quaternion)
            imu_payload = {
                "connected": bool(imu.flags & IMU_INITIALIZED)
                and bool(imu.flags & IMU_SAMPLE_VALID)
                and roll is not None,
                "rollDeg": roll,
                "pitchDeg": pitch,
                "yawDeg": yaw,
                "quaternionW": _finite(quaternion[0]),
                "quaternionX": _finite(quaternion[1]),
                "quaternionY": _finite(quaternion[2]),
                "quaternionZ": _finite(quaternion[3]),
                "ageMs": None
                if imu.last_rx_age_us == 0xFFFFFFFF
                else imu.last_rx_age_us / 1000.0,
                "sampleCounter": imu.sample_counter,
                "accuracy": imu.accuracy,
            }
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

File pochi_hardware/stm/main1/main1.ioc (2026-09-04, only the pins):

Mcu.UserName=STM32G474CBTx
PA1.GPIO_Label=LED_PWM2
PA1.Signal=S_TIM2_CH2
PA10.GPIO_Label=RS485_RX
PA10.Signal=USART1_RX
PA11.Signal=FDCAN1_RX
PA12.GPIO_Label=RS485_DE
PA12.Signal=USART1_DE
PA13.Signal=SYS_JTMS-SWDIO
PA14.Signal=SYS_JTCK-SWCLK
PA15.GPIO_Label=LED_PWM1
PA15.Signal=S_TIM2_CH1
PA2.GPIO_Label=JTAG_TX
PA2.Signal=USART2_TX
PA3.GPIO_Label=JTAG_RX
PA3.Signal=USART2_RX
PA4.GPIO_Label=SPI_Slave_NSS
PA4.Signal=SPI1_NSS
PA5.GPIO_Label=SPI_Slave_SCK
PA5.Signal=SPI1_SCK
PA6.GPIO_Label=SPI_Slave_MISO
PA6.Signal=SPI1_MISO
PA7.GPIO_Label=SPI_Slave_MOSI
PA7.Signal=SPI1_MOSI
PA8.GPIO_Label=SPI_Master_INT
PA8.Signal=GPIO_Input
PA9.GPIO_Label=RS485_TX
PA9.Signal=USART1_TX
PB10.GPIO_Label=TTL_TX
PB10.Signal=USART3_TX
PB11.GPIO_Label=TTL_RX
PB11.Signal=USART3_RX
PB12.GPIO_Label=SPI_Master_NSS
PB12.Signal=SPI2_NSS
PB13.GPIO_Label=SPI_Master_SCK
PB13.Signal=SPI2_SCK
PB14.GPIO_Label=SPI_Master_MISO
PB14.Signal=SPI2_MISO
PB15.GPIO_Label=SPI_Master_MOSI
PB15.Signal=SPI2_MOSI
PB2.GPIO_Label=LED_CPU
PB2.Signal=GPIO_Output
PB3.Signal=FDCAN3_RX
PB4.Signal=FDCAN3_TX
PB5.Signal=FDCAN2_RX
PB6.Signal=FDCAN2_TX
PB8-BOOT0.GPIO_Label=BOOT0
PB8-BOOT0.Signal=GPIO_Input
PB9.Signal=FDCAN1_TX
PF0-OSC_IN.Signal=RCC_OSC_IN
PF1-OSC_OUT.Signal=RCC_OSC_OUT

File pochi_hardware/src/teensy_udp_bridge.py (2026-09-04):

#!/usr/bin/env python3
from __future__ import annotations

import argparse
import socket
import time

import serial

from pochi_client.protocol import (
    CobsStreamDecoder,
    ProtocolError,
    decode_command,
    decode_state,
    encode_usb_frame,
)


def endpoint(value: str) -> tuple[str, int]:
    host, separator, port = value.rpartition(":")
    if not separator:
        raise argparse.ArgumentTypeError("endpoint must be HOST:PORT")
    return host, int(port)


def main() -> None:
    parser = argparse.ArgumentParser(description="Pochi Teensy USB/UDP bridge")
    parser.add_argument("--serial", default="/dev/ttyACM0", help="Teensy USB serial device")
    parser.add_argument("--baud", type=int, default=115200, help="nominal USB CDC baud rate")
    parser.add_argument("--command-bind", type=endpoint, default=("0.0.0.0", 15000))
    parser.add_argument("--state-dest", type=endpoint, default=("127.0.0.1", 15001))
    args = parser.parse_args()

    udp = socket.socket(socket.AF_INET, socket.SOCK_DGRAM)
    udp.bind(args.command_bind)
    udp.setblocking(False)
    decoder = CobsStreamDecoder()

    with serial.Serial(args.serial, args.baud, timeout=0, write_timeout=0) as teensy:
        while True:
            did_work = False
            waiting = teensy.in_waiting
            if waiting:
                frames = decoder.feed(teensy.read(waiting))
            else:
                frames = []
            for frame in frames:
                try:
                    decode_state(frame)
                except ProtocolError:
                    continue
                udp.sendto(frame, args.state_dest)
                did_work = True

            while True:
                try:
                    command, _source = udp.recvfrom(2048)
                except BlockingIOError:
                    break
                try:
                    decode_command(command)
                except ProtocolError:
                    continue
                teensy.write(encode_usb_frame(command))
                did_work = True

            if not did_work:
                time.sleep(0.0005)


if __name__ == "__main__":
    try:
        main()
    except KeyboardInterrupt:
        pass

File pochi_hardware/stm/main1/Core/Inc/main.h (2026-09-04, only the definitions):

#define JTAG_TX_Pin GPIO_PIN_2
#define JTAG_TX_GPIO_Port GPIOA
#define JTAG_RX_Pin GPIO_PIN_3
#define JTAG_RX_GPIO_Port GPIOA
#define SPI_Slave_NSS_Pin GPIO_PIN_4
#define SPI_Slave_NSS_GPIO_Port GPIOA
#define SPI_Slave_SCK_Pin GPIO_PIN_5
#define SPI_Slave_SCK_GPIO_Port GPIOA
#define SPI_Slave_MISO_Pin GPIO_PIN_6
#define SPI_Slave_MISO_GPIO_Port GPIOA
#define SPI_Slave_MOSI_Pin GPIO_PIN_7
#define SPI_Slave_MOSI_GPIO_Port GPIOA
#define SPI_Master_MOSI_Pin GPIO_PIN_12
#define SPI_Master_MOSI_GPIO_Port GPIOB
#define SPI_Master_SCK_Pin GPIO_PIN_13
#define SPI_Master_SCK_GPIO_Port GPIOB
#define SPI_Master_MISO_Pin GPIO_PIN_14
#define SPI_Master_MISO_GPIO_Port GPIOB
#define SPI_Master_MOSIB15_Pin GPIO_PIN_15
#define SPI_Master_MOSIB15_GPIO_Port GPIOB
#define LED_PWM1_Pin GPIO_PIN_8
#define LED_PWM1_GPIO_Port GPIOA
#define LED_PWM2_Pin GPIO_PIN_9
#define LED_PWM2_GPIO_Port GPIOA
#define LED_MCU_Pin GPIO_PIN_10
#define LED_MCU_GPIO_Port GPIOA
#define TTL_RX_Pin GPIO_PIN_8
#define TTL_RX_GPIO_Port GPIOB
#define TTL_TX_Pin GPIO_PIN_9
#define TTL_TX_GPIO_Port GPIOB

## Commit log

2026-08-30 feat(hardware): add Pochi electronics, firmware, communication tools, and web controller
    [MCU.kicad_sch, Power.kicad_sch, main_1.kicad_pcb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]
2026-09-01 Refactor code structure for improved readability and maintainability
    [Body_pipe1_2_x__25_15_1_5_134_x4_.stl, Body_pipe2_y__25_15_1_5_300_x4_.stl, Body_pipe3_2_z__15_15_1_5_112_x4_.stl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]
2026-09-04 feat(hardware): add calibrated telemetry and remote deployment
2026-09-04 feat(firmware): blink LED on Orin communication
2026-09-04 feat(hardware): add safe MIT motor controls
2026-09-04 Add stand-up task: scripted controller and learned policy
    Pochi can now get up off its belly, two ways.
    - `control/` is a new backend-neutral, pure-numpy layer: planar two-link
    FK/IK for one leg, and a scripted stand-up that ramps base height in
    Cartesian space and solves it back into joint targets, closed on joint
    encoders only so the same code runs on hardware. `mujoco_driver.py`
    runs it against `scene_flat.xml`; `scripts/play_standup.py` serves it
    over viser.
    - `Pochi-StandUp-Flat-v0` is the learned version: the robot resets into
    `COLLAPSED_JOINT_POS` on the floor and has to rise. It uses
    `POCHI_SLOW_ROBOT_CFG`, the speed-limited actuator whose envelope
    (2 rad/s no-load,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

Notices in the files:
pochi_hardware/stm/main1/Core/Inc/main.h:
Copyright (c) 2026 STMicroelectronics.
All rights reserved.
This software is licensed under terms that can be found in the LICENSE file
